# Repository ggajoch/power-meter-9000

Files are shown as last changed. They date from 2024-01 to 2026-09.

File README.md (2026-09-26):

# What is power meter 9000?

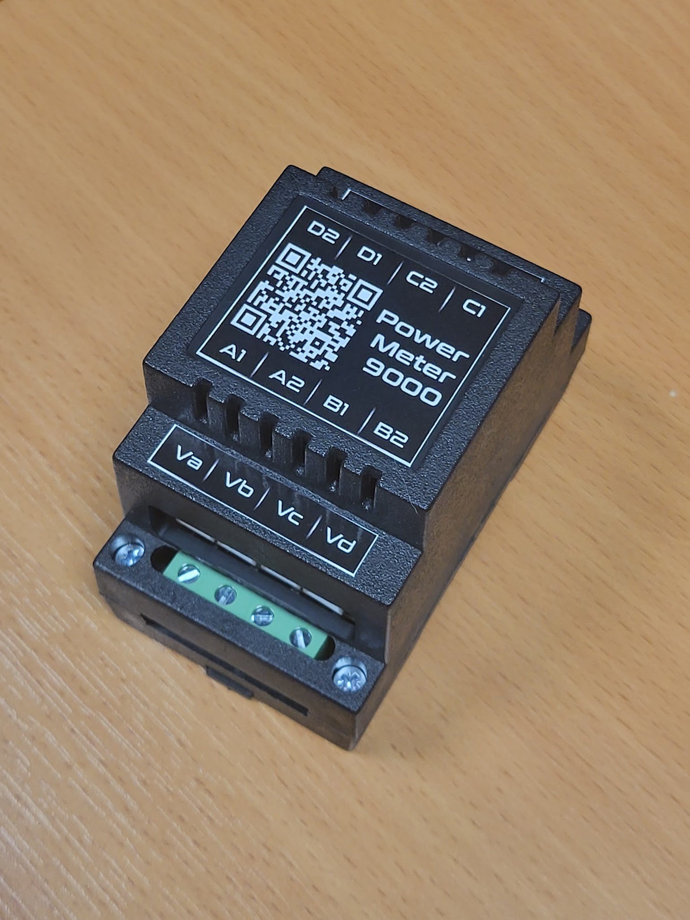
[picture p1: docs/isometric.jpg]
isometric view


Power Meter 9000 is a device to measure power drawn by electrical devices in your house. It can measure up to 8 current channels, each with 20 A current capability.

# Architecture

Power meter 9000 consists of 4 measurement channels (A, B, C, D), each with 1 voltage measurement and 2 current/power channels (total of 8 power measurements). Each channel uses BL0939 IC.

To get correct active power measurements, the current channel needs to be connected to the same phase as the corresponding voltage channels.

For example, if you have dishwasher on L1 phase, TV on L1, homelab on L2 and PC on L3 you should connect:
 - L1 to Va
 - L2 to Vb
 - L3 to Vc
 - dishwasher clamp to A1
 - TV clamp to A2
 - homelab clamp to B1
 - pc clamp to C1

Device is supplied by integrated AC-DC power supply, with power input on channel Va.

ESP32-S2 is a brain of the power meter, running esphome. Schematics/PCBs are in the repo.

# How to connect it?

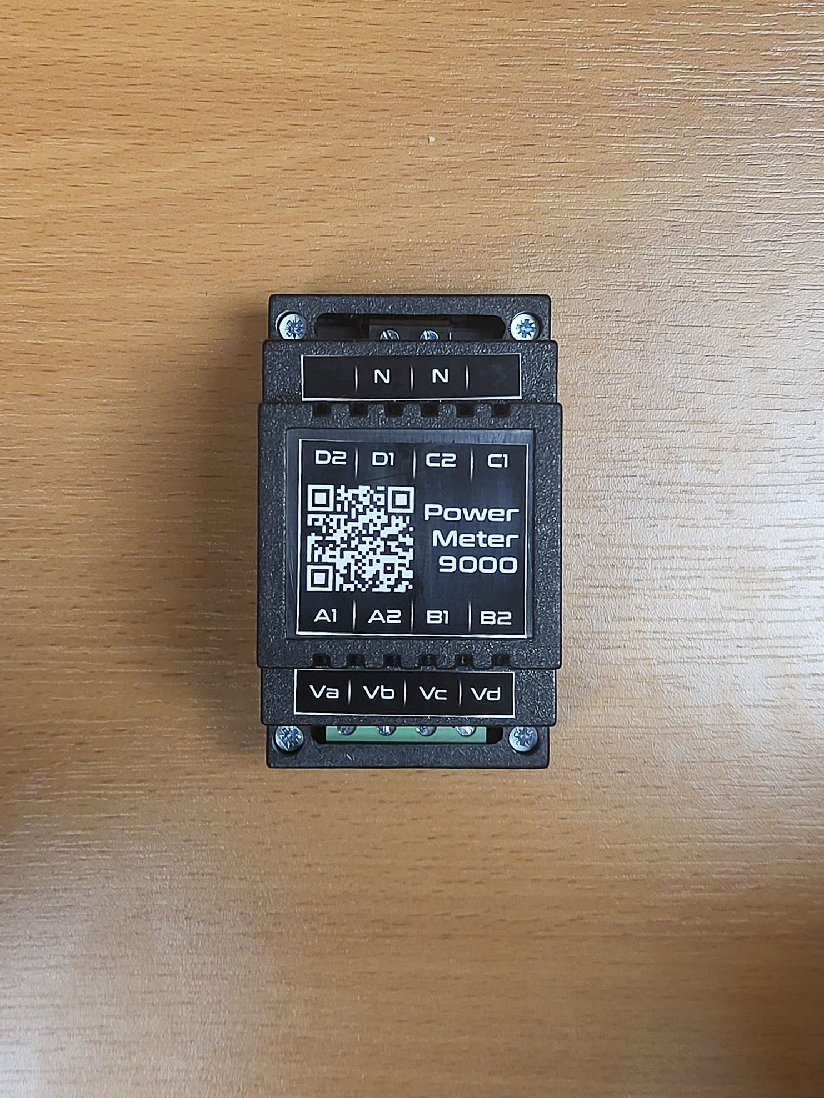
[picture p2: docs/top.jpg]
top view


 - decide on the power lines you want to measure
 - connect neutral to top terminal (either one - they are connected internally, and there are two if you would want to daisy-chain the power meters 9000)
 - for each power line, find the corresponding phase it belongs to (L1, L2, L3)
 - connect voltage inputs to corresponding terminals (Va, Vb, Vc, Vd)
 - install current clamps on the measurement lines
 - connect clamps to corresponding current input lines

# Software

Device has [`power-meter-9000.yaml`](esphome/power-meter-9000.yaml) flashed by default.

This means that the device has captive portal by default with its Wi-Fi in AP mode.

To change Wi-Fi credentials and connect to home assistant:
 - power on the device
 - connect to the Wi-Fi of the device (`power-meter-9000` with password `power-meter-9000`)
 - change Wi-Fi credentials
 - device should be discovered in Home Assistant

# But I want to flash it normally!

Sure, just **disconnect it from mains power before connecting it to computer**, undo 4 screws and connect USB to the ESP32 module. To start in bootloader, press user button during reset.

You can use https://adafruit.github.io/Adafruit_WebSerial_ESPTool/ or just esphome command line tool.

# FAQ

## My device reset itself and just don't appear on Wi-Fi

Have you re-flashed your device?

Due to the bug in the ESP32S2 modules, Wi-Fi power needs to be brought down to around 8.5 - 11 - 15 dBm for stable operation (varies on the specific copy and Wi-Fi coverage).

If you still have problems, turn the output power down.

## Weak Wi-Fi signal in electrical cabinet

By default, output_power of Wi-Fi is set to 11 dBm. If you have weak Wi-Fi, you may try increasing output_power to 15 dBm and see if that would help.

## I get correct reading of current, but power is not measured correctly

Have you connected properly current clamp to the same phase as the corresponding voltage input?

## Energy went negative or jumped after around 850 kWh

Firmware before PR #4 (September 2026) read the BL0939 energy counter as a signed 24-bit value, so a channel flipped negative after 2^23 pulses (about 851 kWh) and wrapped to 0 at about 1702 kWh. Update the firmware: the counter is now accumulated on the ESP with wrap handling, so energy grows without limit.

Negative energy is still valid when a clamp sees power flowing the other way, for example a grid feed with PV export. Energy is counted net: import adds, export subtracts.

## Energy resets to 0 after a reboot or OTA

By design. The chip keeps counting across an ESP reboot, but the firmware cannot tell how the counter got there, so every boot starts energy at 0. Home Assistant treats it as a meter reset (`total_increasing`) and keeps long-term statistics continuous. Only the consumption during the reboot itself is lost.

If a channel's energy jumps by more than `max_power` (default 10000 W per channel) times the time since the last reading, the firmware assumes the chip reset its counter (brownout) and continues from the new value. Set `max_power` on the `bl0939addr` platform if a single channel can exceed 10 kW.

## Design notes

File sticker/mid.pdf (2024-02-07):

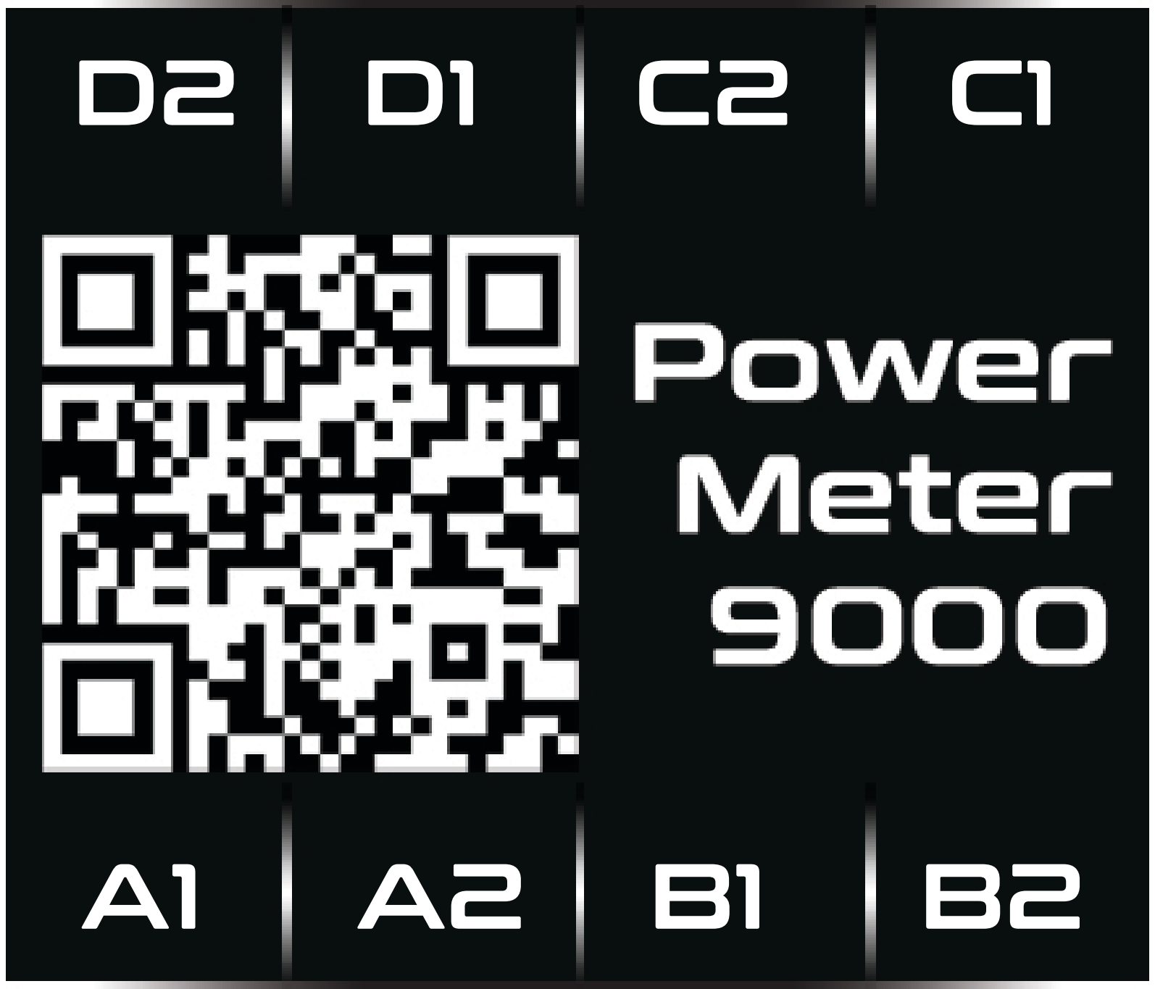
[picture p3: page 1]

D2 D1 C2 C1

A1 A2 B1 B2

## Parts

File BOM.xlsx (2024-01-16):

what? | pcs per unit | price per unit (PLN) |  | to order |  | USD/PLN | 4.02
LOWER PCB |  |  |  |  |  | units | 50
PCB from JLCPCB | 1 | 21.047916 |  |  |  | total usd to pln per unit | 0.0804
long goldpins | 1 | 0.31356 | https://pl.aliexpress.com/item/1005003012878518.html | 1
fuse | 1 | 1.371624 | https://pl.aliexpress.com/item/1005005627617019.html | 10
UPPER PCB
PCB from JLCPCB | 1 | 30.969276
goldpins 6pin | 1 | 0.471948 | https://pl.aliexpress.com/item/1005001913376271.html | 6 | TOTAL | 50pcs | unit | unit (sell 30)
ESP32 S2 | 1 | 6.947364 | https://www.aliexpress.us/item/1005006404455505.html | 50 |  | 5185.8838 | 103.717676 | 172.8627933
CURRENT TRANSFORMER
CT08CL10 | 8 | 32.16
OTHERS
nylon standoffs + screw + nut | 3 | 1.138464 | https://pl.aliexpress.com/item/1005006038666758.html | 8
self-tap screw 3x10 | 2 | 0.547524 | https://pl.aliexpress.com/item/1005006219858361.html | 3
Z102 case | 1 | 8.75 | https://www.kradex.com.pl/product/obudowy_modulowe_na_szyne_din/z102?lang=pl#options | 50

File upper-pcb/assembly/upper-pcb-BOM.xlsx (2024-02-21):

Comment | Designator | Footprint | JLCPCB Part #（optional）
C_33nF_50V_X7R_0603_10 | C1_CH1, C1_CH2, C1_CH3, C1_CH4, C2_CH1, C2_CH2, C2_CH3, C2_CH4, C3_CH1, C3_CH2, C3_CH3, C3_CH4, C4_CH1, C4_CH2, C4_CH3, C4_CH4, C5_CH1, C5_CH2, C5_CH3, C5_CH4, C7_CH1, C7_CH2, C7_CH3, C7_CH4, C8_CH1, C8_CH2, C8_CH3, C8_CH4 | C_0603_1608 | C21117
C_100nF_50V_X7R_0603_5 | C6_CH1, C6_CH2, C6_CH3, C6_CH4, C9, C10 | C_0603_1608 | C14663
P_HEADER_2x8_2.54_VERTICAL | M1, M2 | P_HEADER_2x8_2.54_VERTICAL | C30734
P_XHB-2AW | P1_CH1, P1_CH2, P1_CH3, P1_CH4, P2_CH1, P2_CH2, P2_CH3, P2_CH4 | P_XHB-2AW | C3011964
R_1k_0603_1 | R1_CH1, R1_CH2, R1_CH3, R1_CH4, R3_CH1, R3_CH2, R3_CH3, R3_CH4, R4_CH1, R4_CH2, R4_CH3, R4_CH4, R6_CH1, R6_CH2, R6_CH3, R6_CH4, R8_CH1, R8_CH2, R8_CH3, R8_CH4 | R_0603_1608 | C21190
R_3.3R_0603_5 | R2_CH1, R2_CH2, R2_CH3, R2_CH4, R5_CH1, R5_CH2, R5_CH3, R5_CH4 | R_0603_1608 | C103612
R_27k_0603_1 | R7_CH1, R7_CH2, R7_CH3, R7_CH4 | R_0603_1608 | C22967
U_BL0939 | U1_CH1, U1_CH2, U1_CH3, U1_CH4 | SSOP20_3.9x8.65 | C2841044
C_10uF_25V_X7S_0805_10 | C11, C12 | C_0805_2012 | C15850
 |  |  |  | Mouser | 603-RC1206FR-07499KL | 0.025 | 0.5 | Warning
 |  |  |  | TME | RC1206FR-07100K |  |  | Fatal error
 |  |  |  | LCSC | C209903 | 2.17 | 2.17 | Error

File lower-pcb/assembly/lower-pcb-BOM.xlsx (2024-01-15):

Comment | Designator | Footprint | JLCPCB Part #（optional）
CE_220uF_16V_AL2O3_10x16x5_20 | C1 | CE_D_10x16x5_THT | C2896719
J_DG128-7.5-02P-14 | J1 | DG128-7.5-02P-14 | C557657
J_DG128-7.5-04P-14 | J2 | DG128-7.5-04P-14 | C2997280
MOV_385VDC_300VAC_THT | MOV1 | MOV_AXIAL_7.5_3.5 | C2839517
R_499k_1206_1 | R1, R2, R3, R4, R5, R7, R8, R9, R10, R11, R13, R14, R15, R16, R17, R19, R20, R21, R22, R23 | R_1206_3216 | C3152280
R_100k_1206_1 | R6, R12, R18, R24, R26, R27, R28, R29 | R_1206_3216 | C17900
VS_HLK-PM01 | U1 | VS_HLK-PMxx | C209903
 |  |  |  | Mouser | 667-EEU-FC1C681 | 0.69 | 0.69 | Warning
 |  |  |  | TME | 883114 |  |  | Fatal error
 |  |  |  | TME | DG128-7.5-02P14 |  |  | Fatal error
 |  |  |  | TME |  |  |  | Fatal error
 |  |  |  | TME | ZL201-06G |  |  | Fatal error
 |  |  |  | Mouser | 603-RC1206FR-07499KL | 0.025 | 0.5 | Warning
 |  |  |  | TME | RC1206FR-07100K |  |  | Fatal error
 |  |  |  | LCSC | C209903 | 2.17 | 2.17 | Error

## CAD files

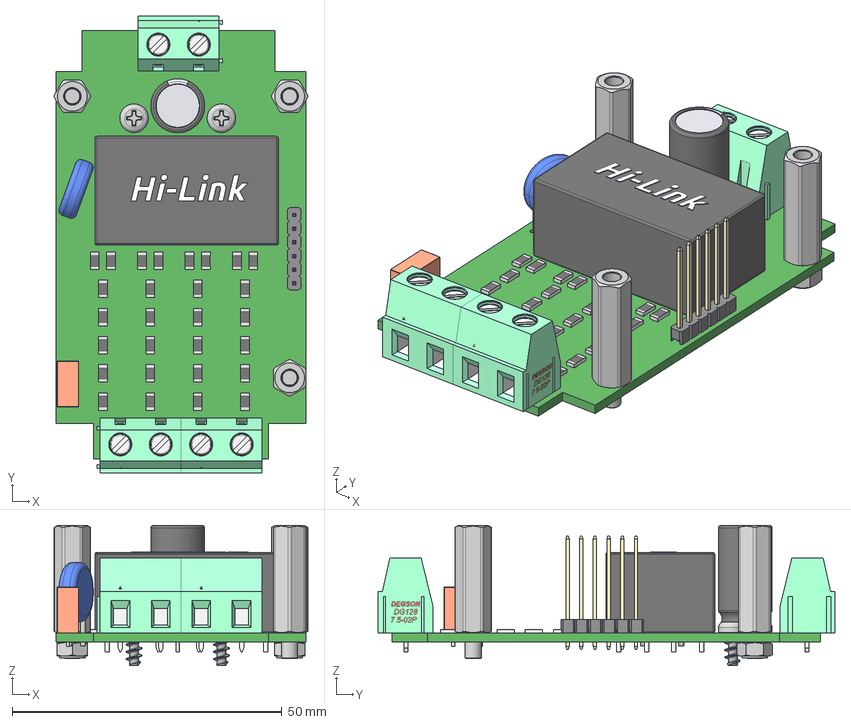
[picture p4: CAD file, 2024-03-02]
lower-pcb/assembly/lower-pcb.step
47.0 x 84.7 x 26.0 mm
te5
RES 1206 (3216 metric) x 28
ElectroCap20x10mm Leads
ElectroCap20x10mm Body
ElectroCap20x10mm Stripe
Hi-Link HiLink HLK-PM v1
DG128-7.5-02P-14-00AH v1 x 3
standoff x 3
m3nut x 2
screw x 2
User Library-MOV-10D561K

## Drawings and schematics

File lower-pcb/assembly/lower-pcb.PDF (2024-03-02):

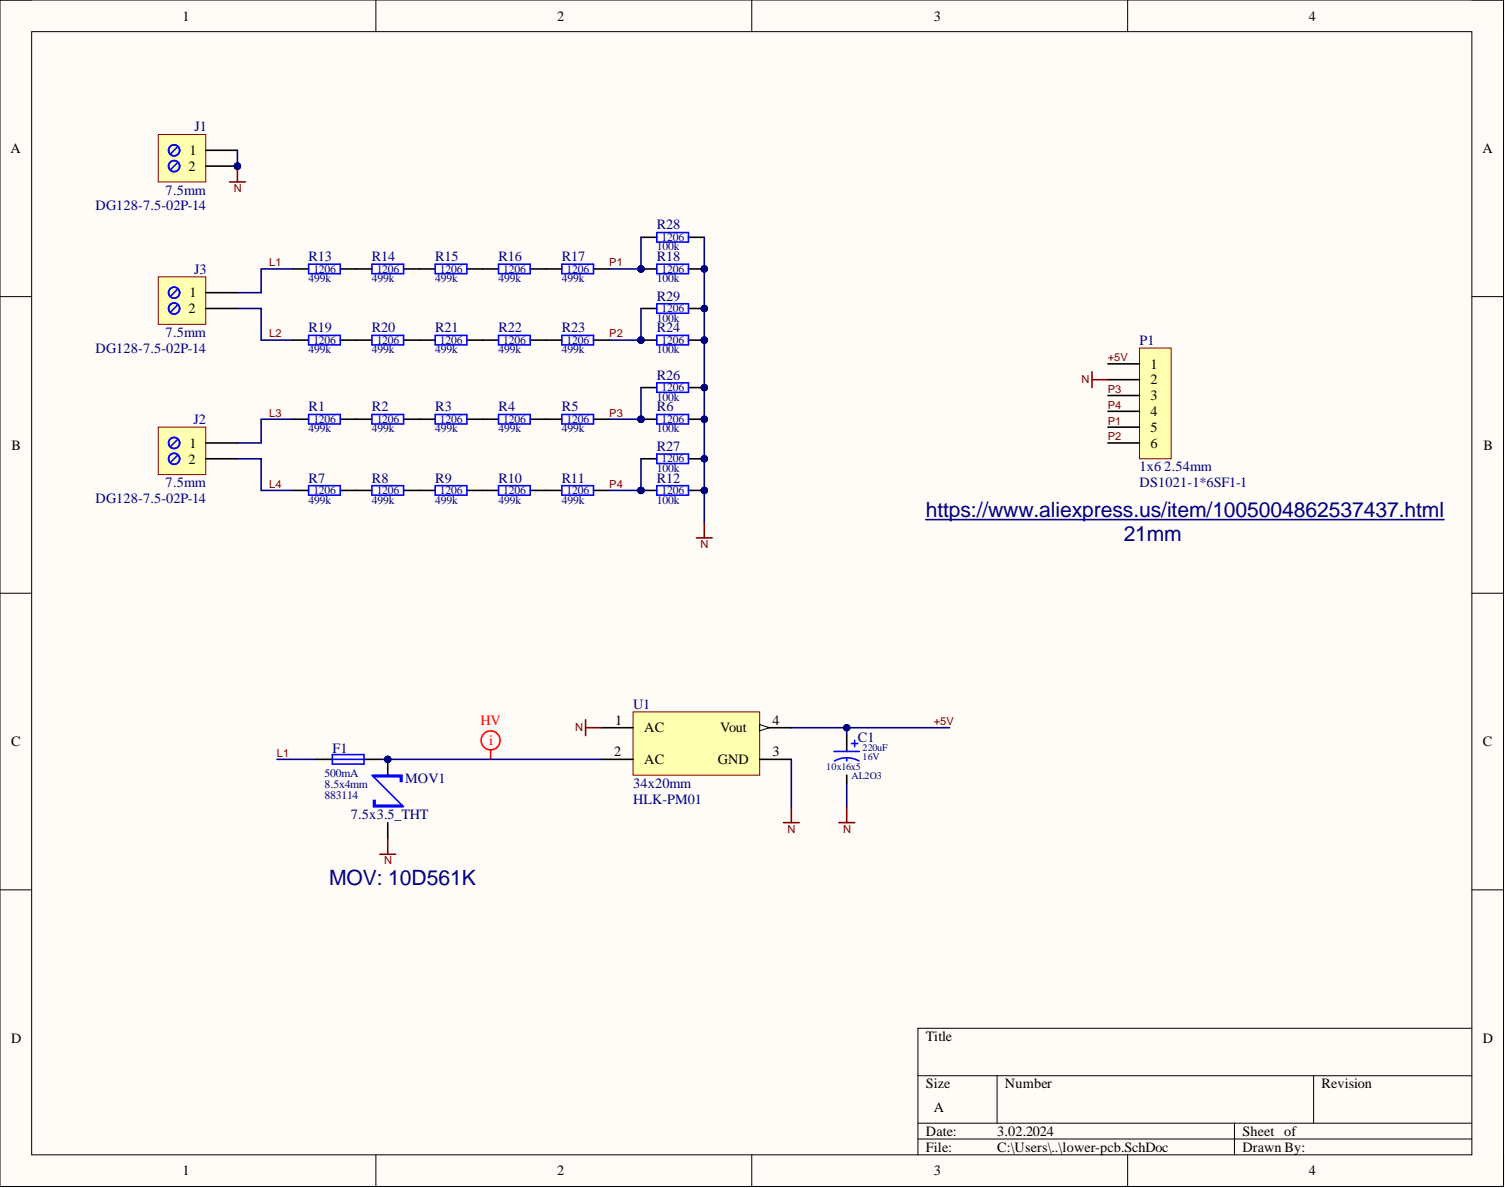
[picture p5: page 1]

https://www.aliexpress.us/item/1005004862537437.html

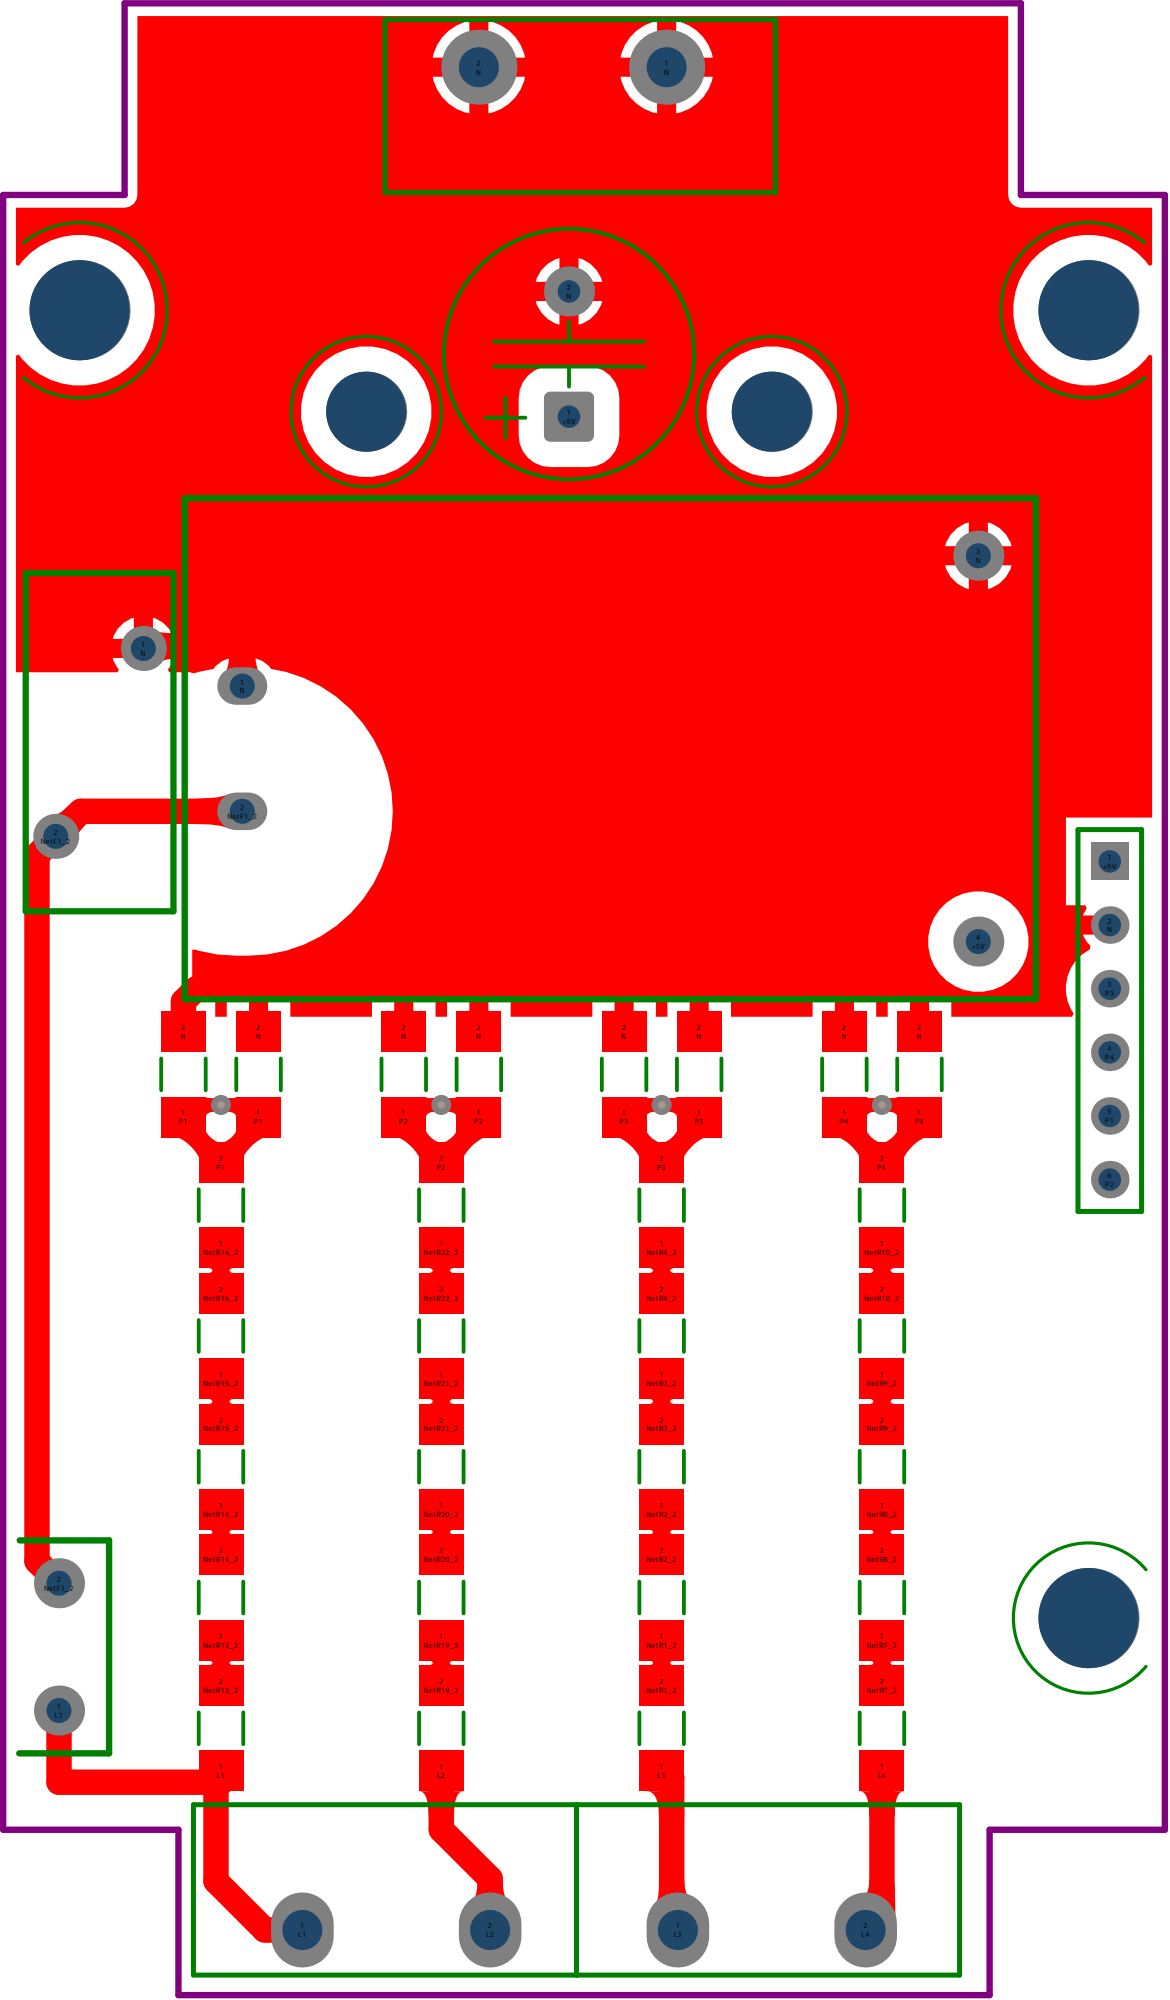
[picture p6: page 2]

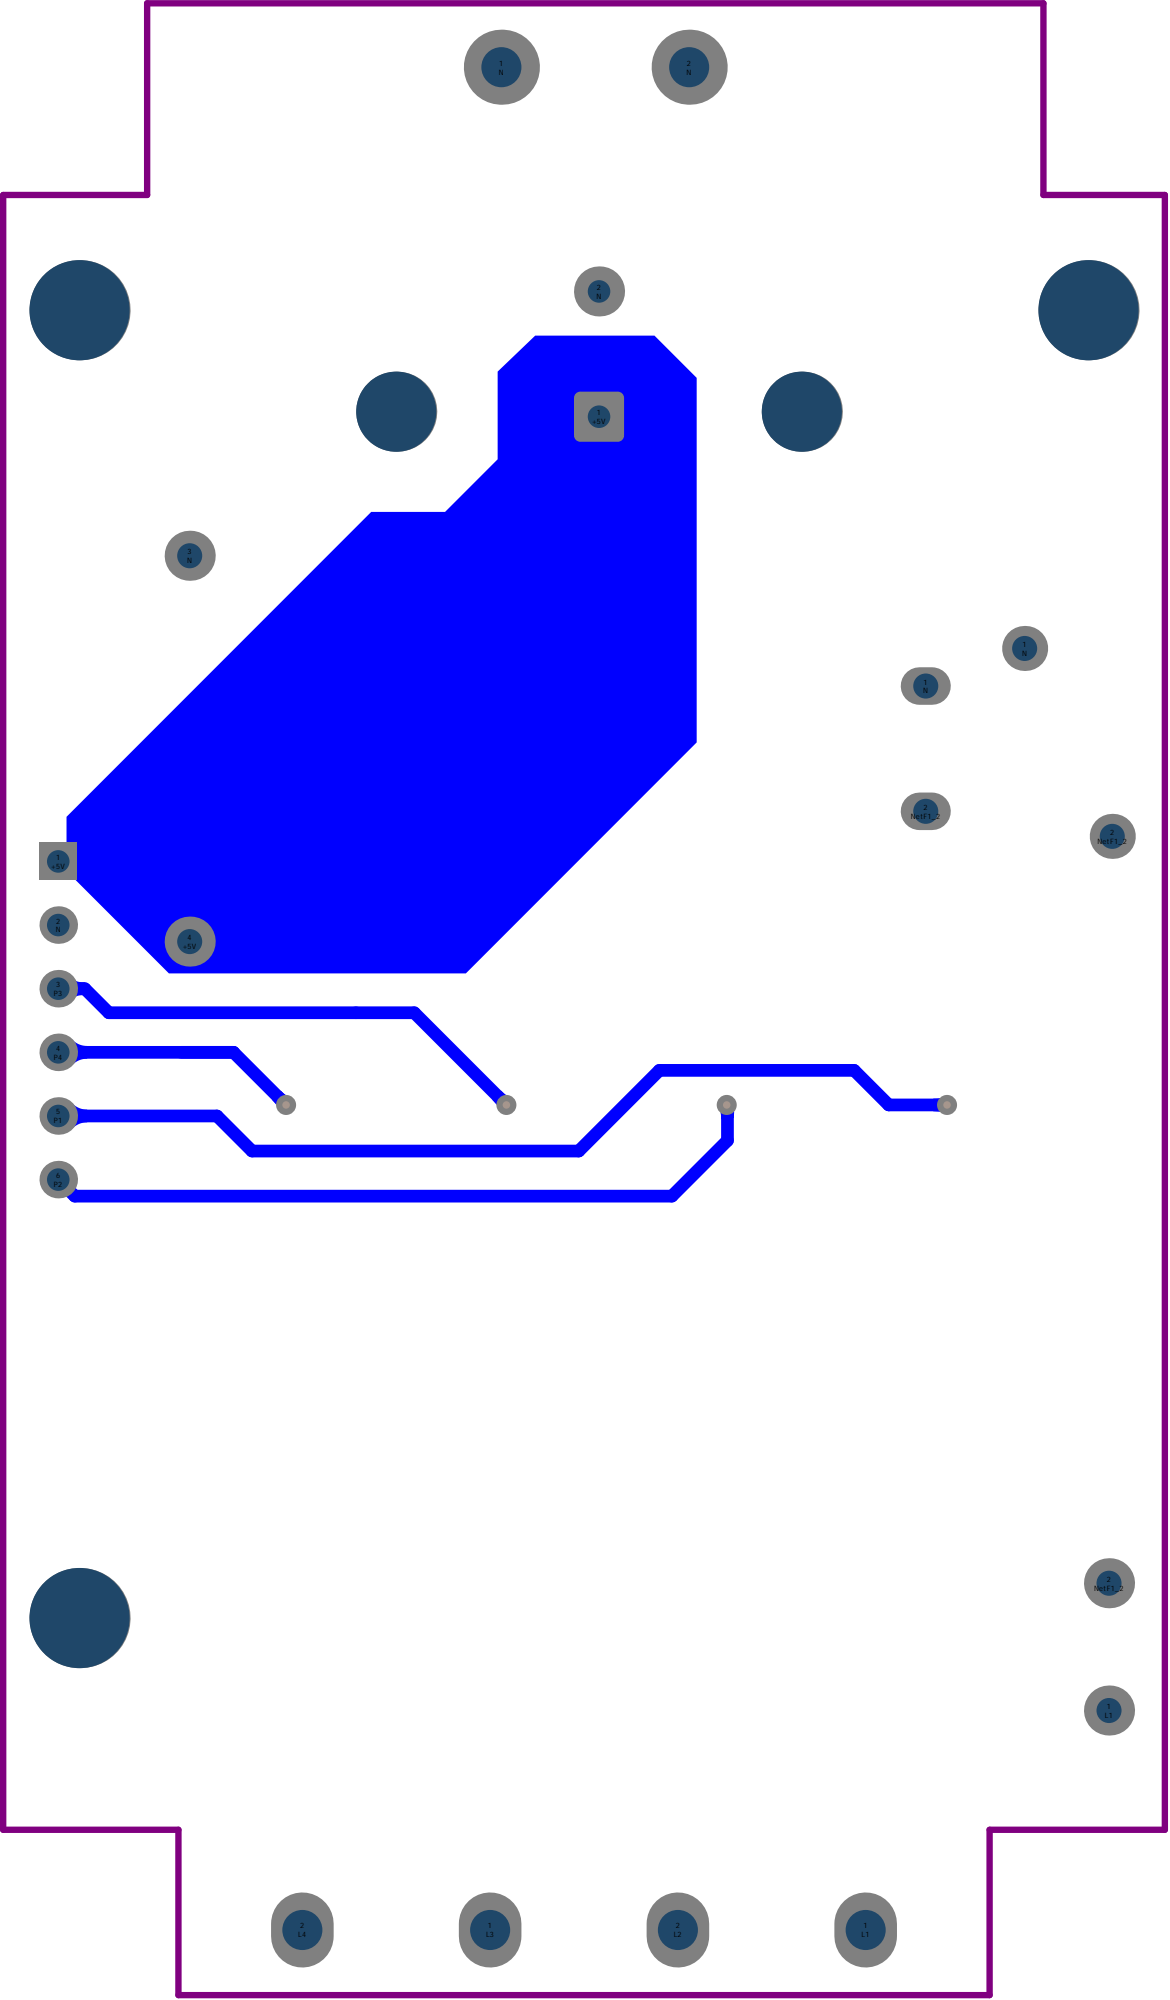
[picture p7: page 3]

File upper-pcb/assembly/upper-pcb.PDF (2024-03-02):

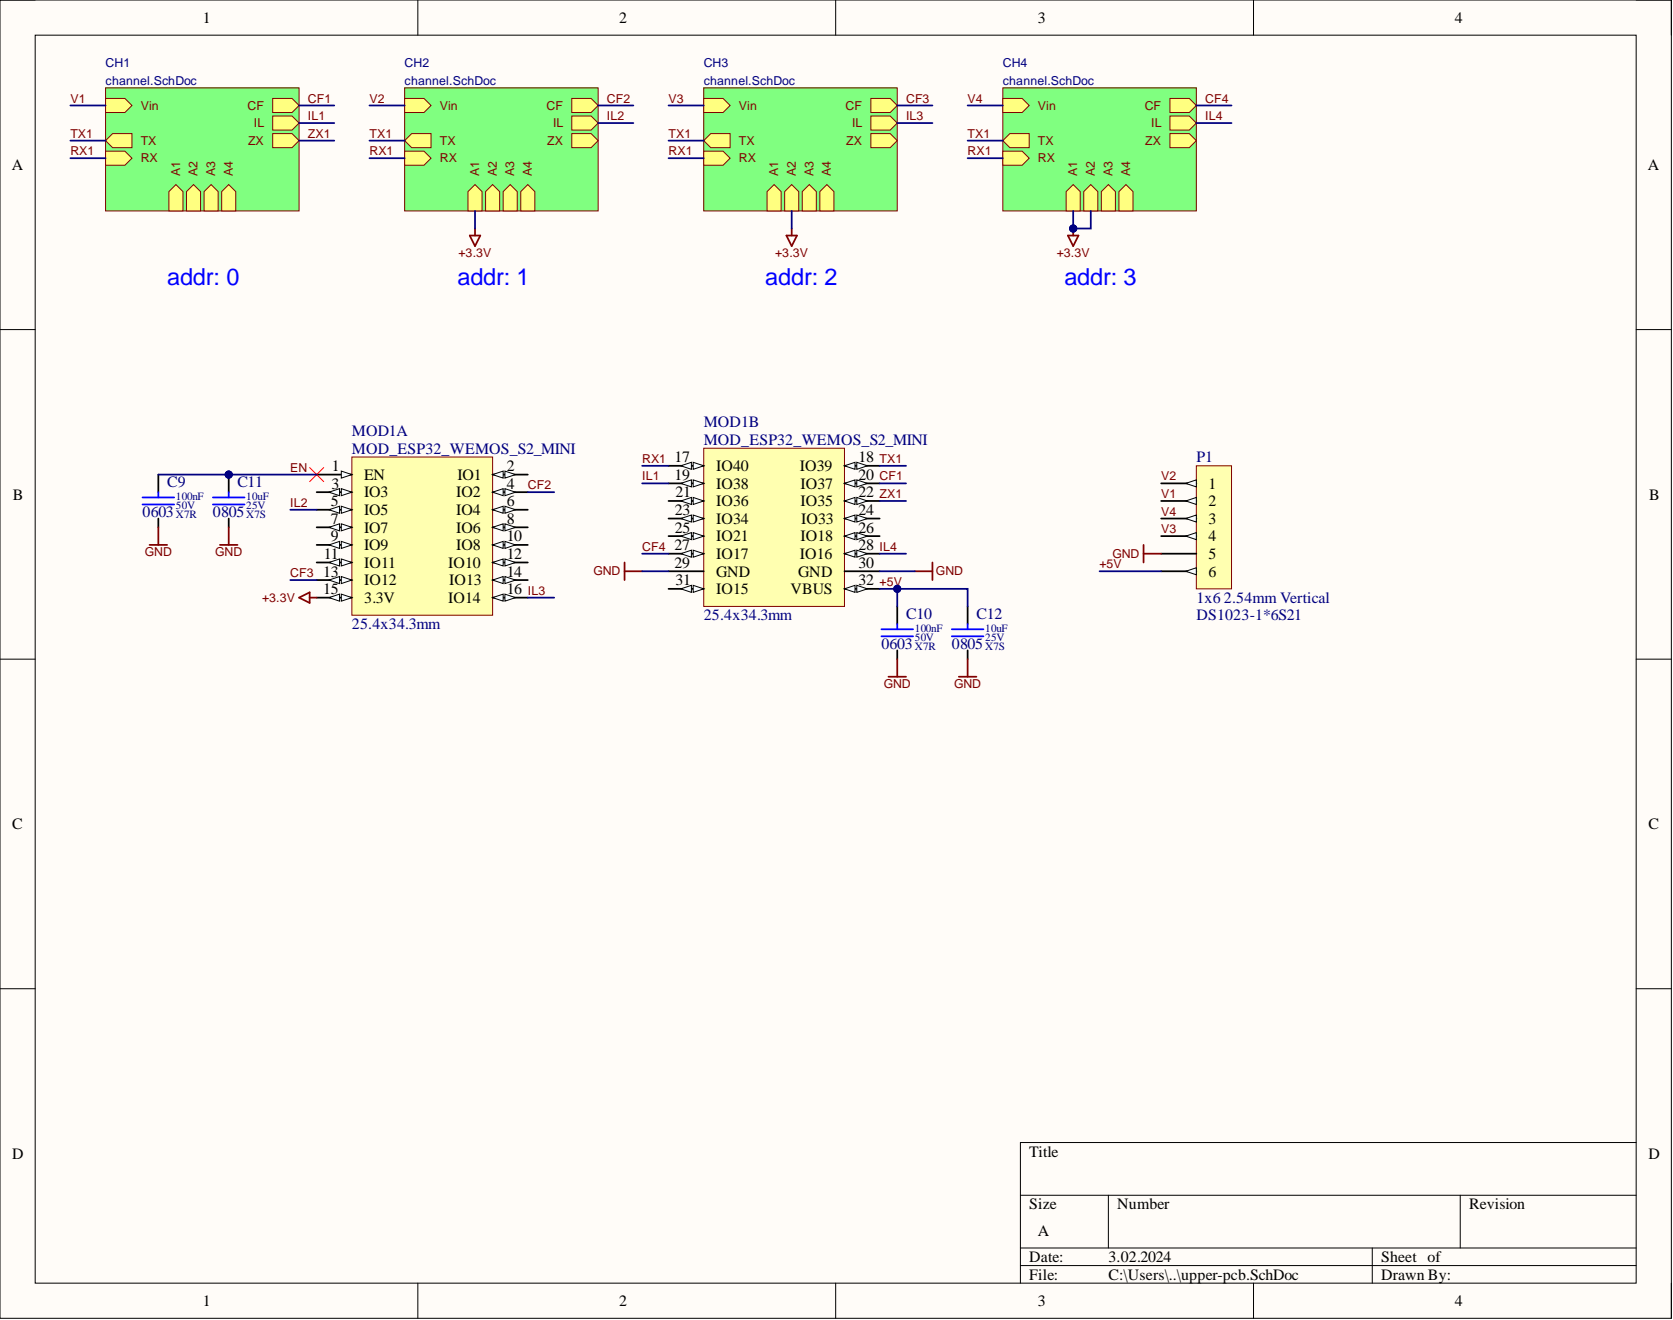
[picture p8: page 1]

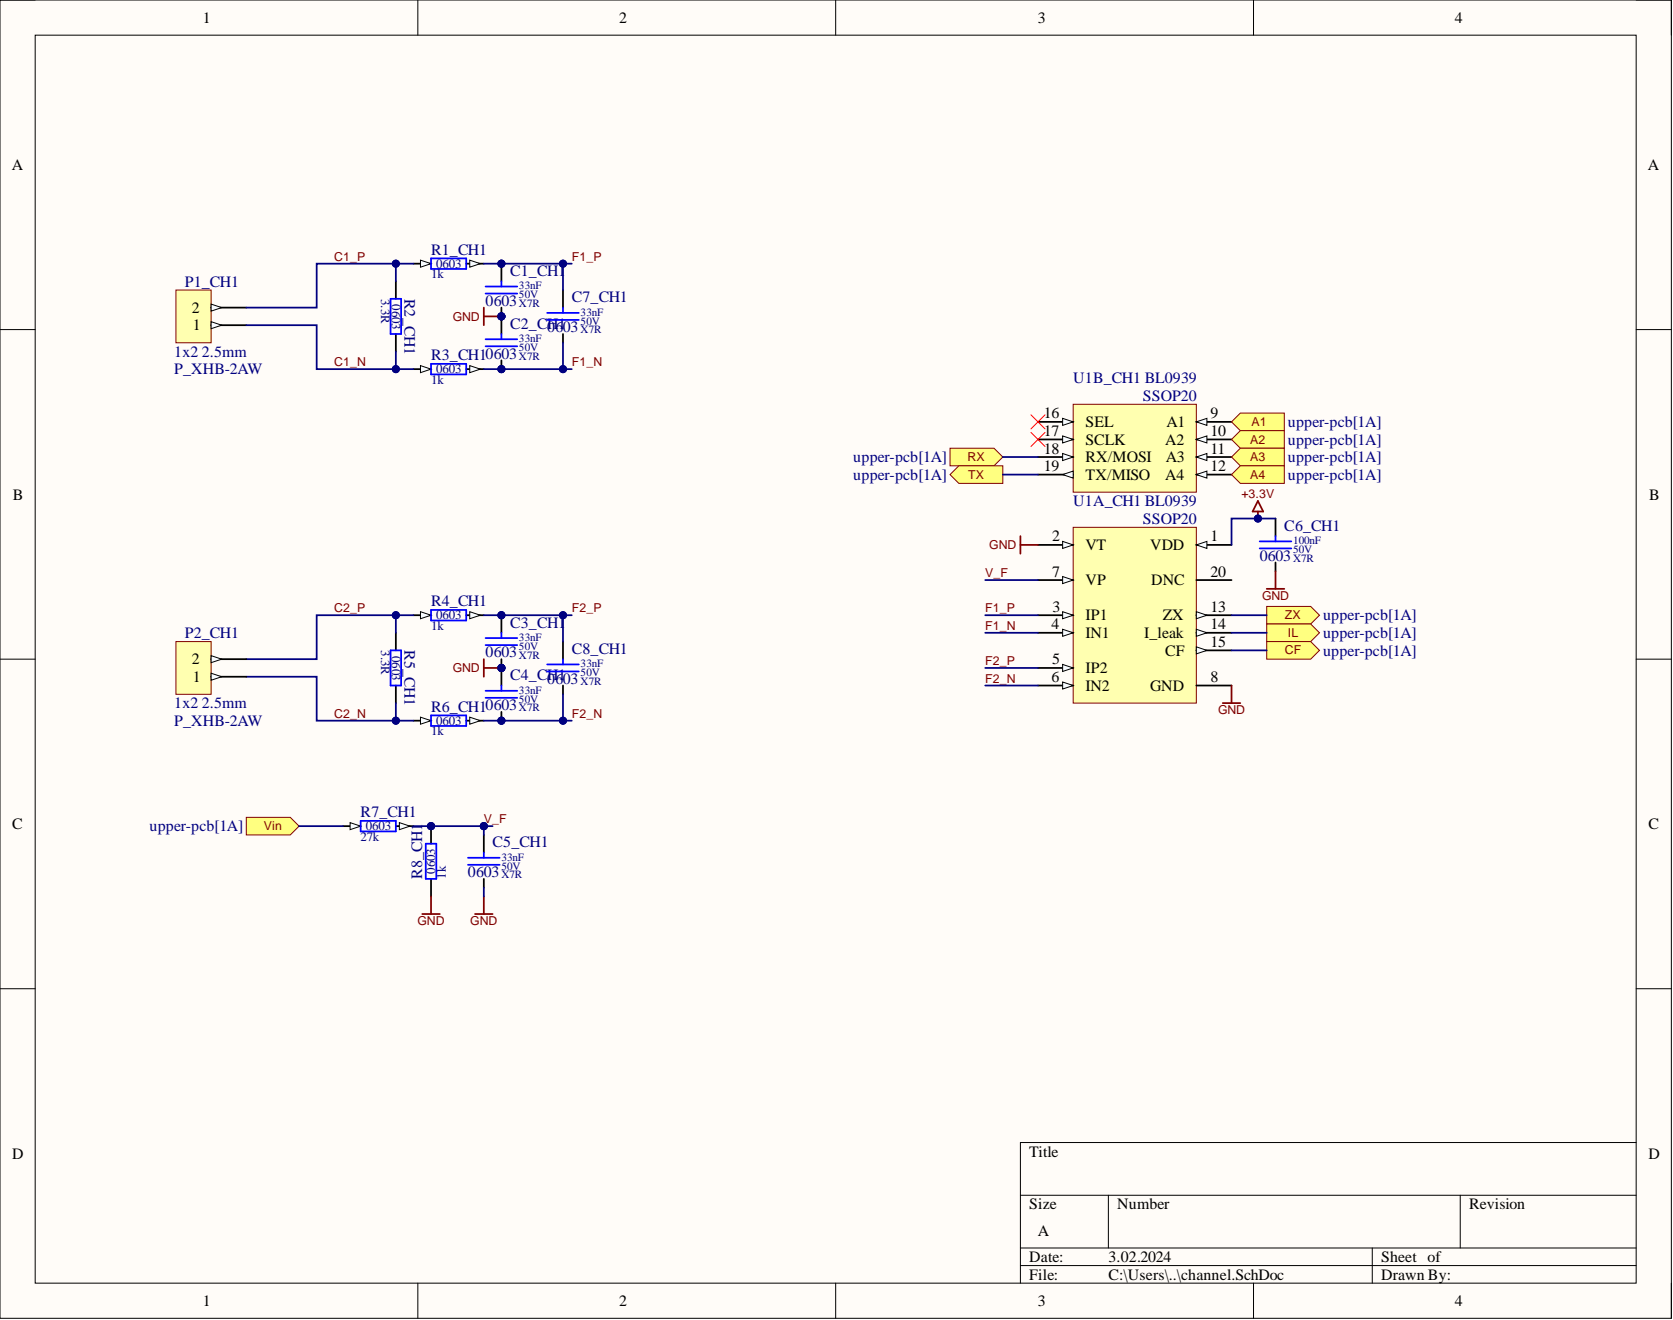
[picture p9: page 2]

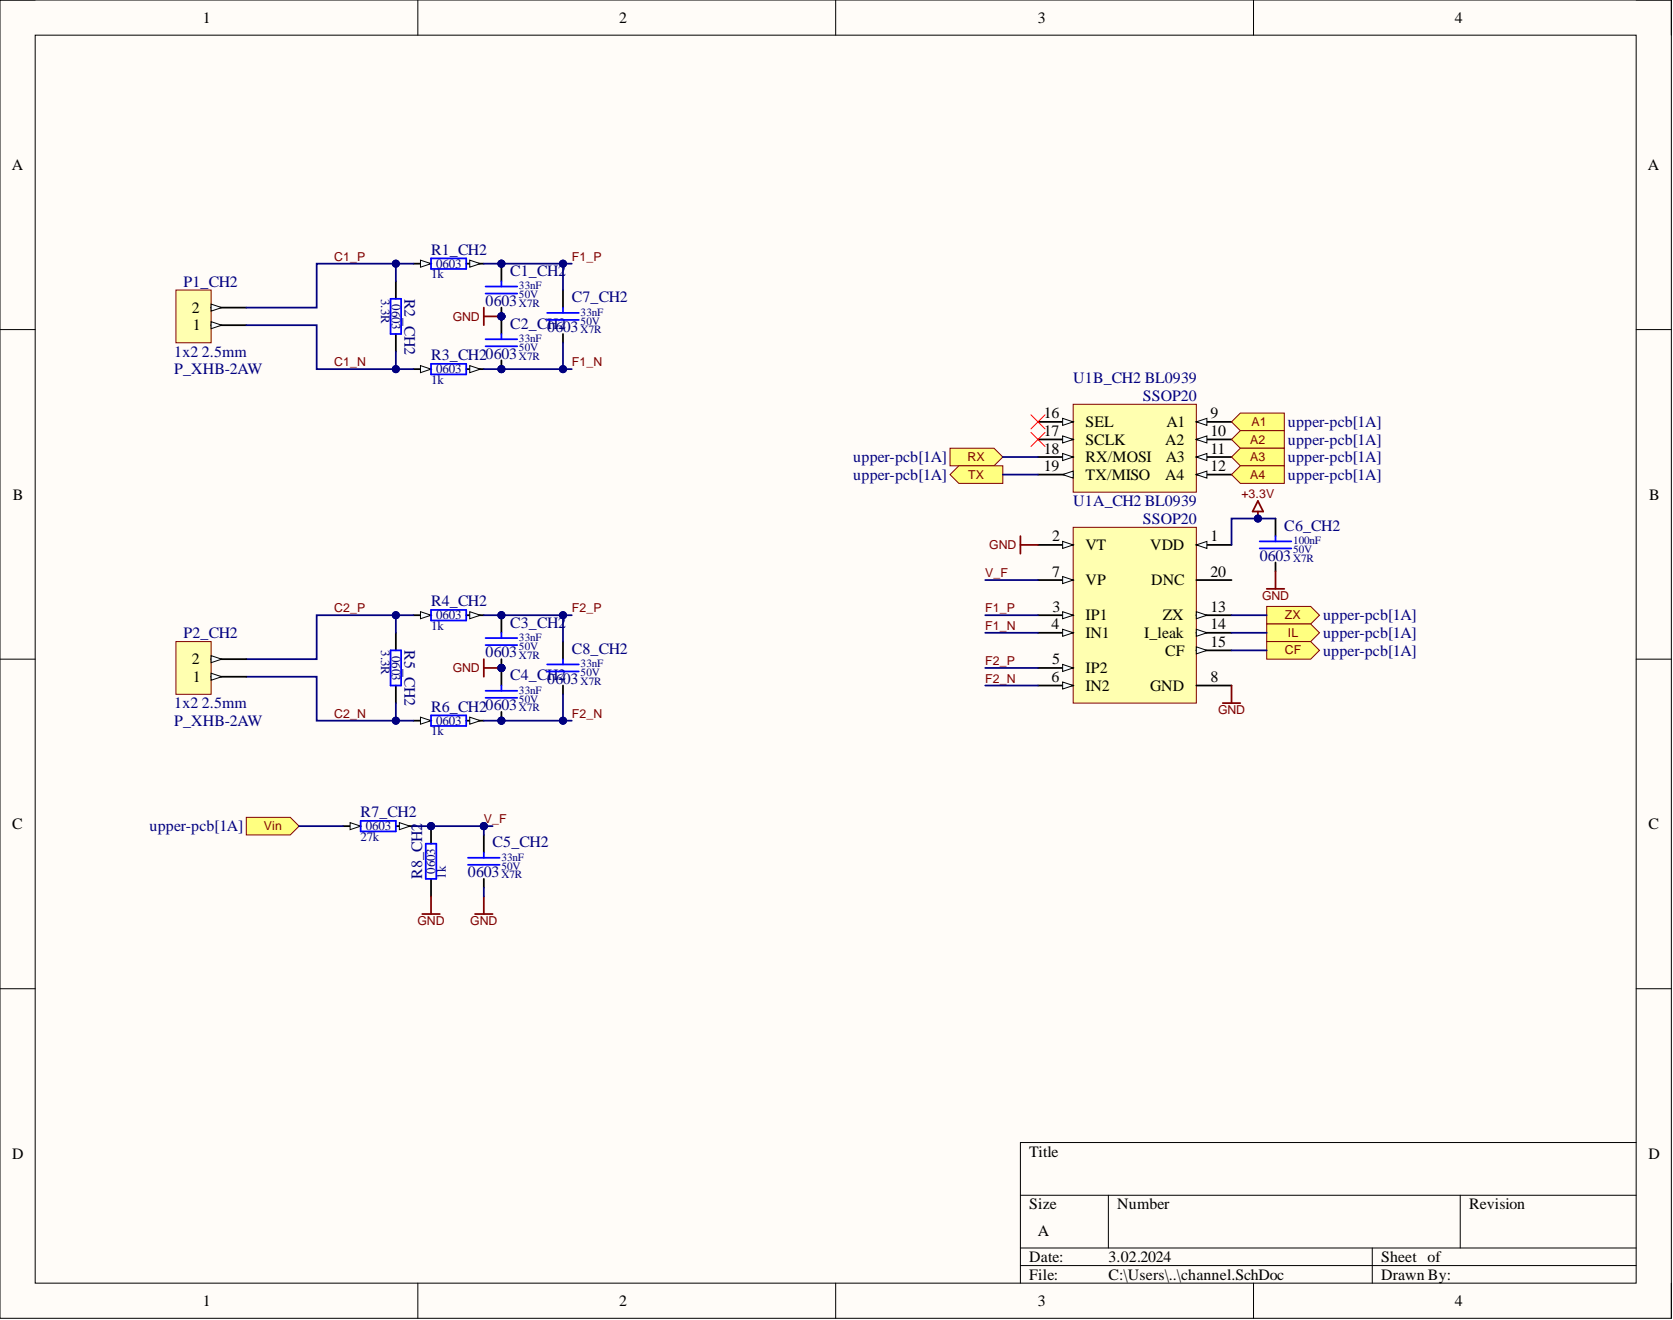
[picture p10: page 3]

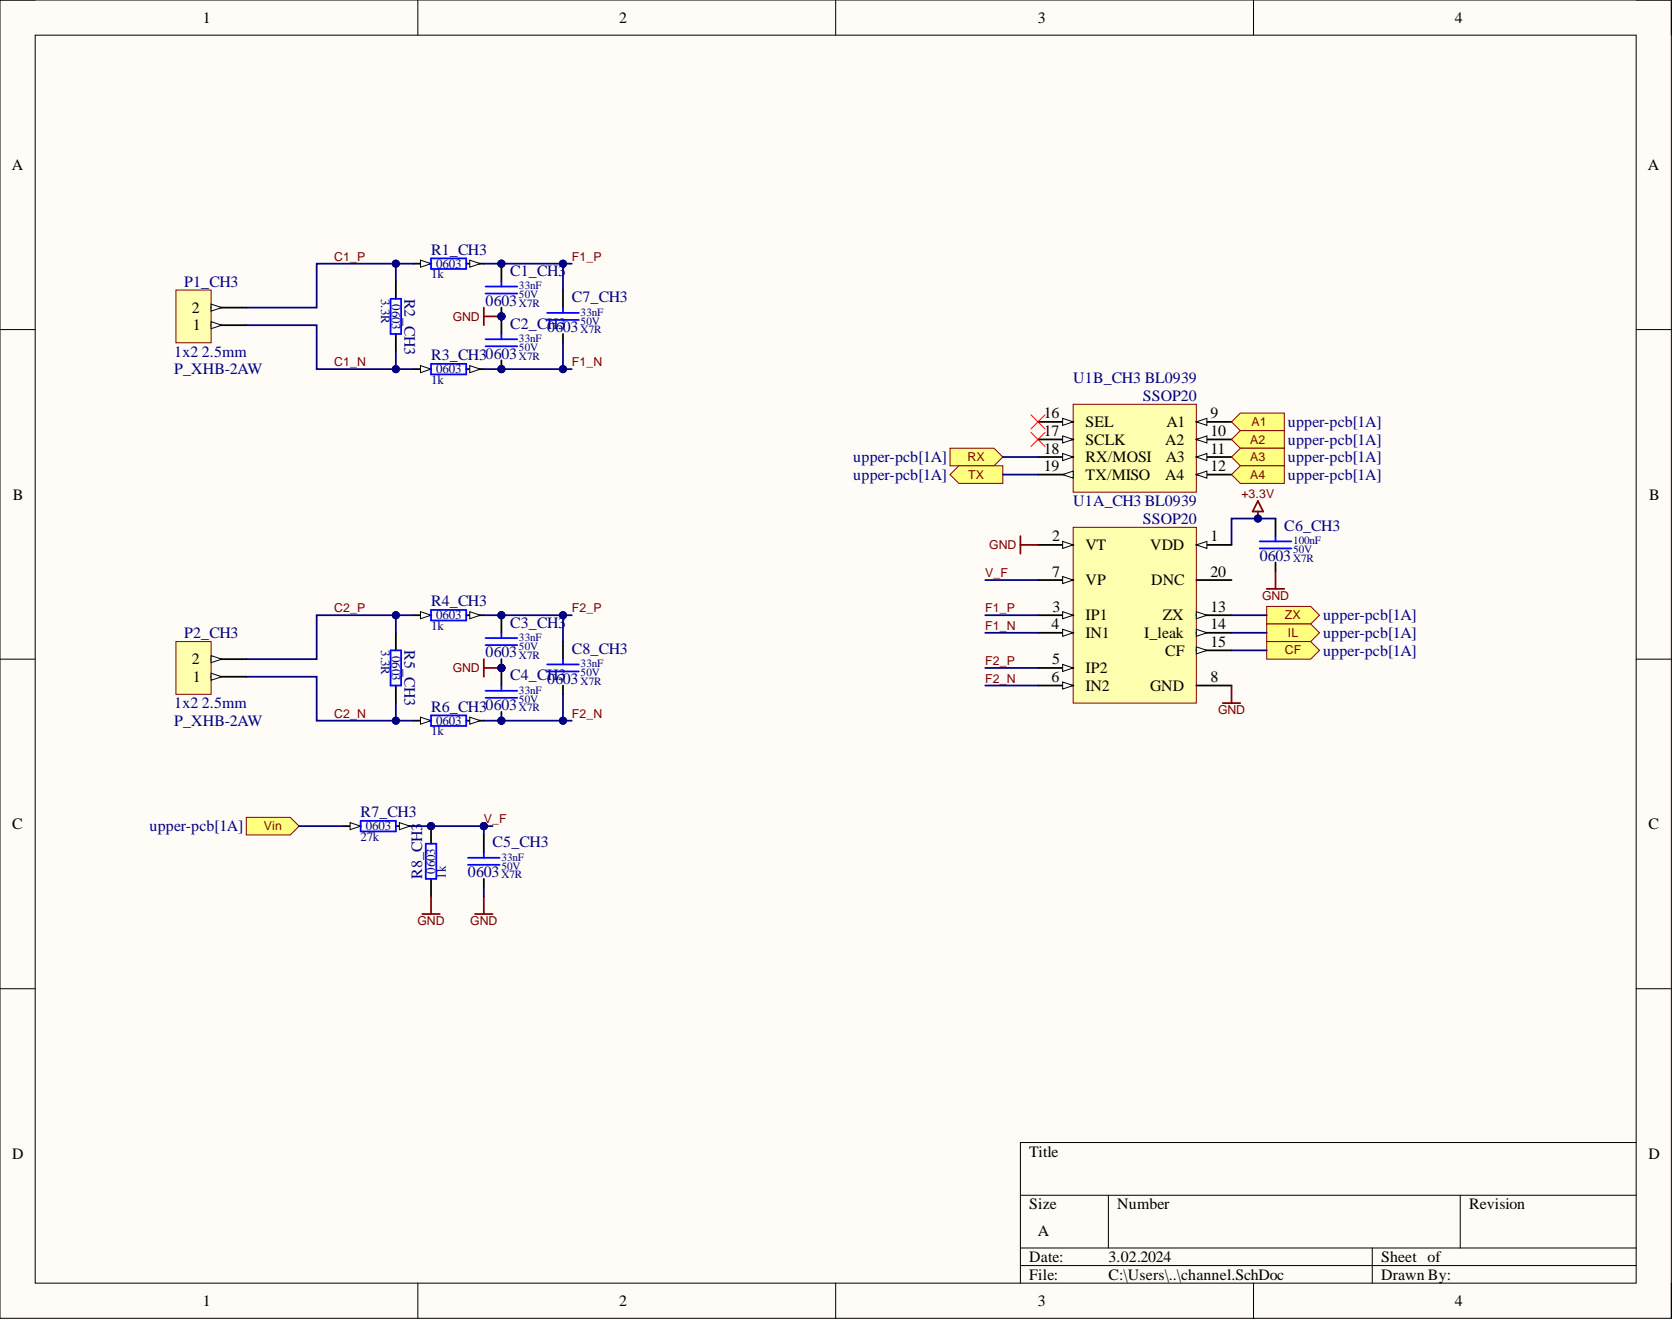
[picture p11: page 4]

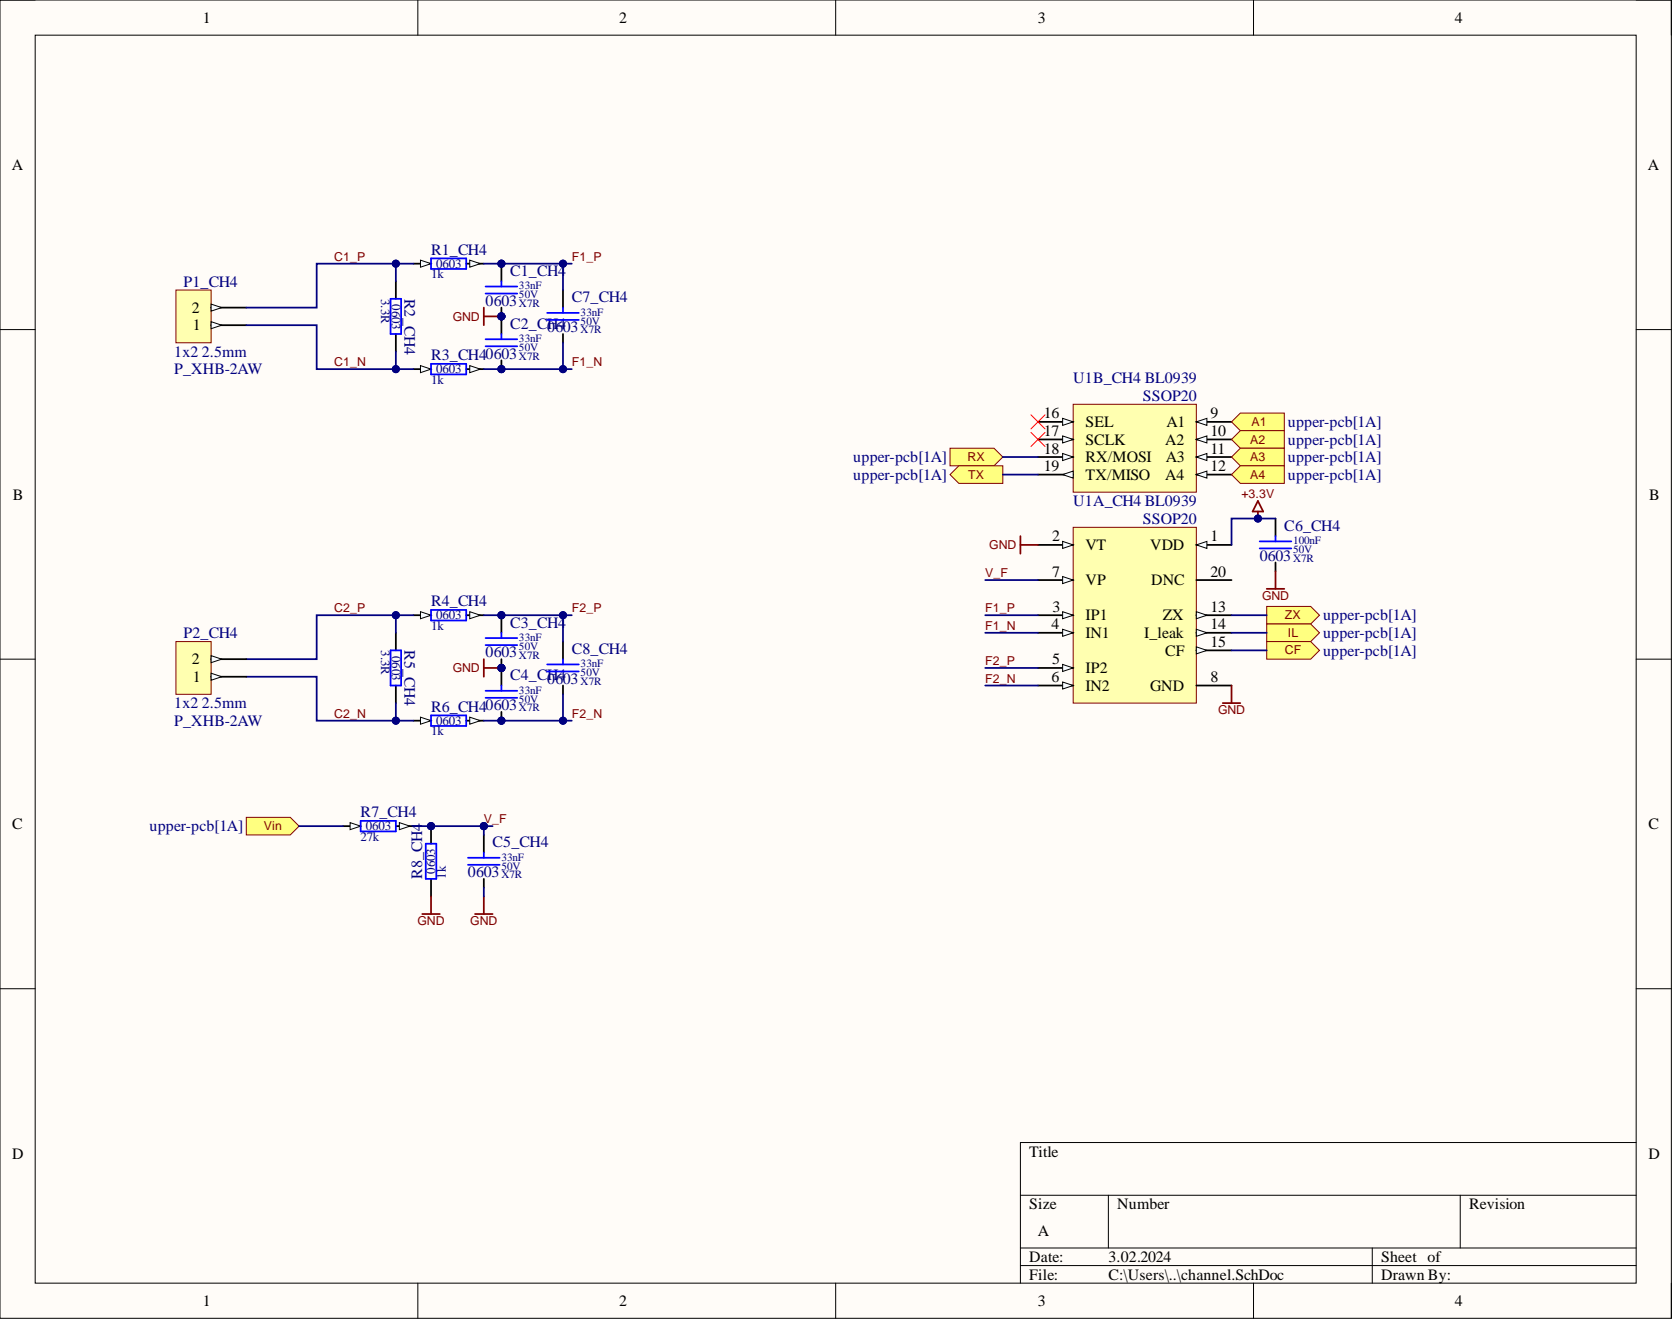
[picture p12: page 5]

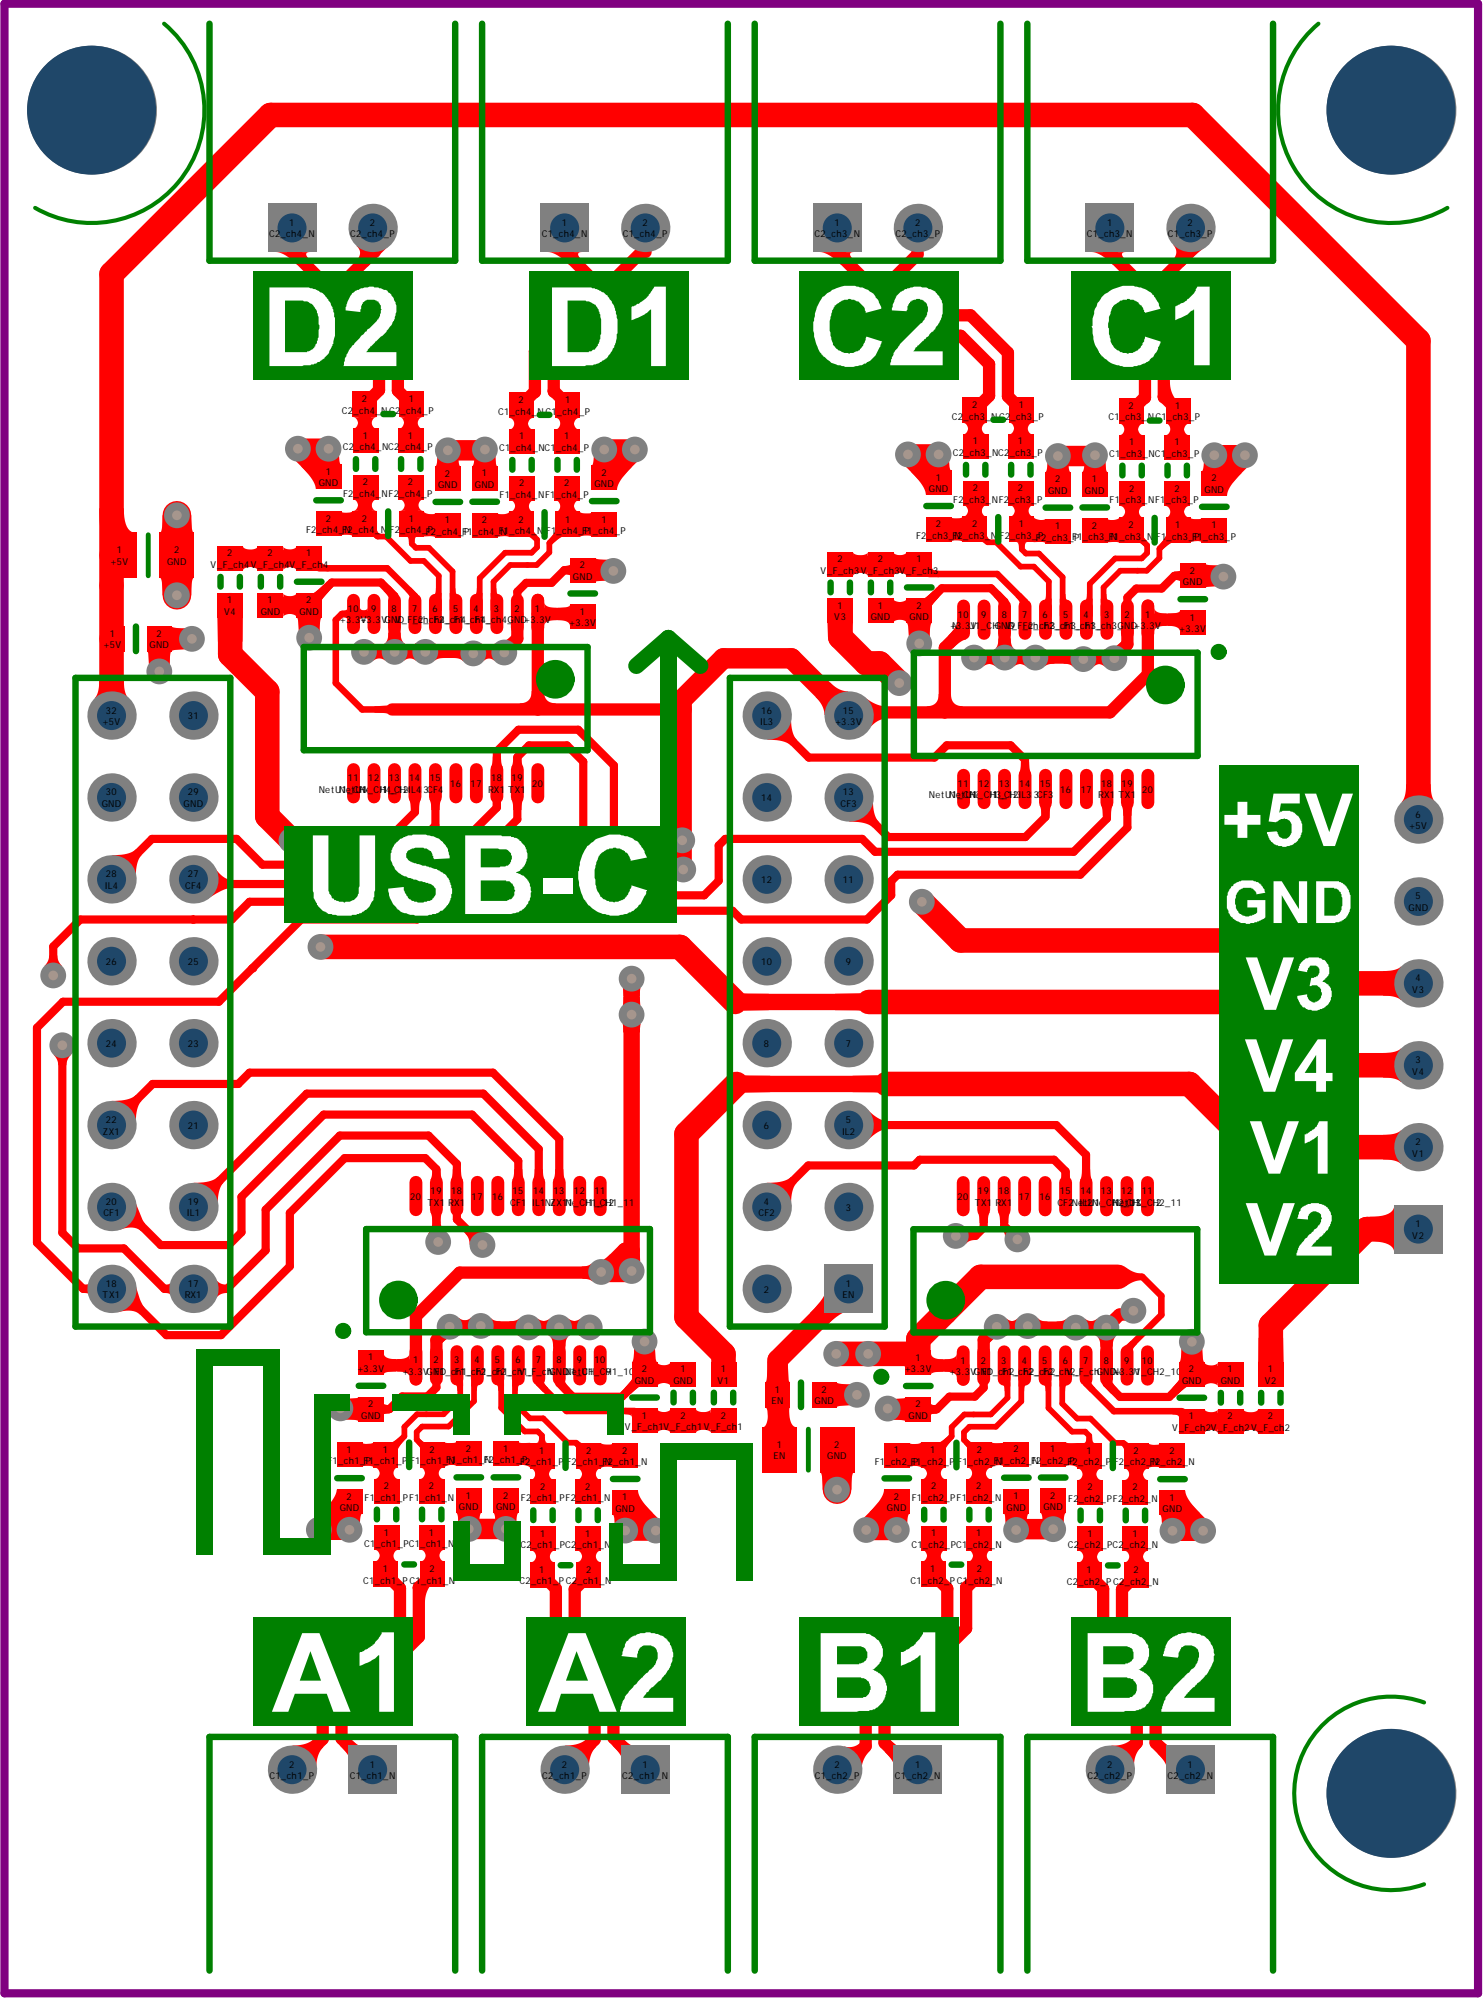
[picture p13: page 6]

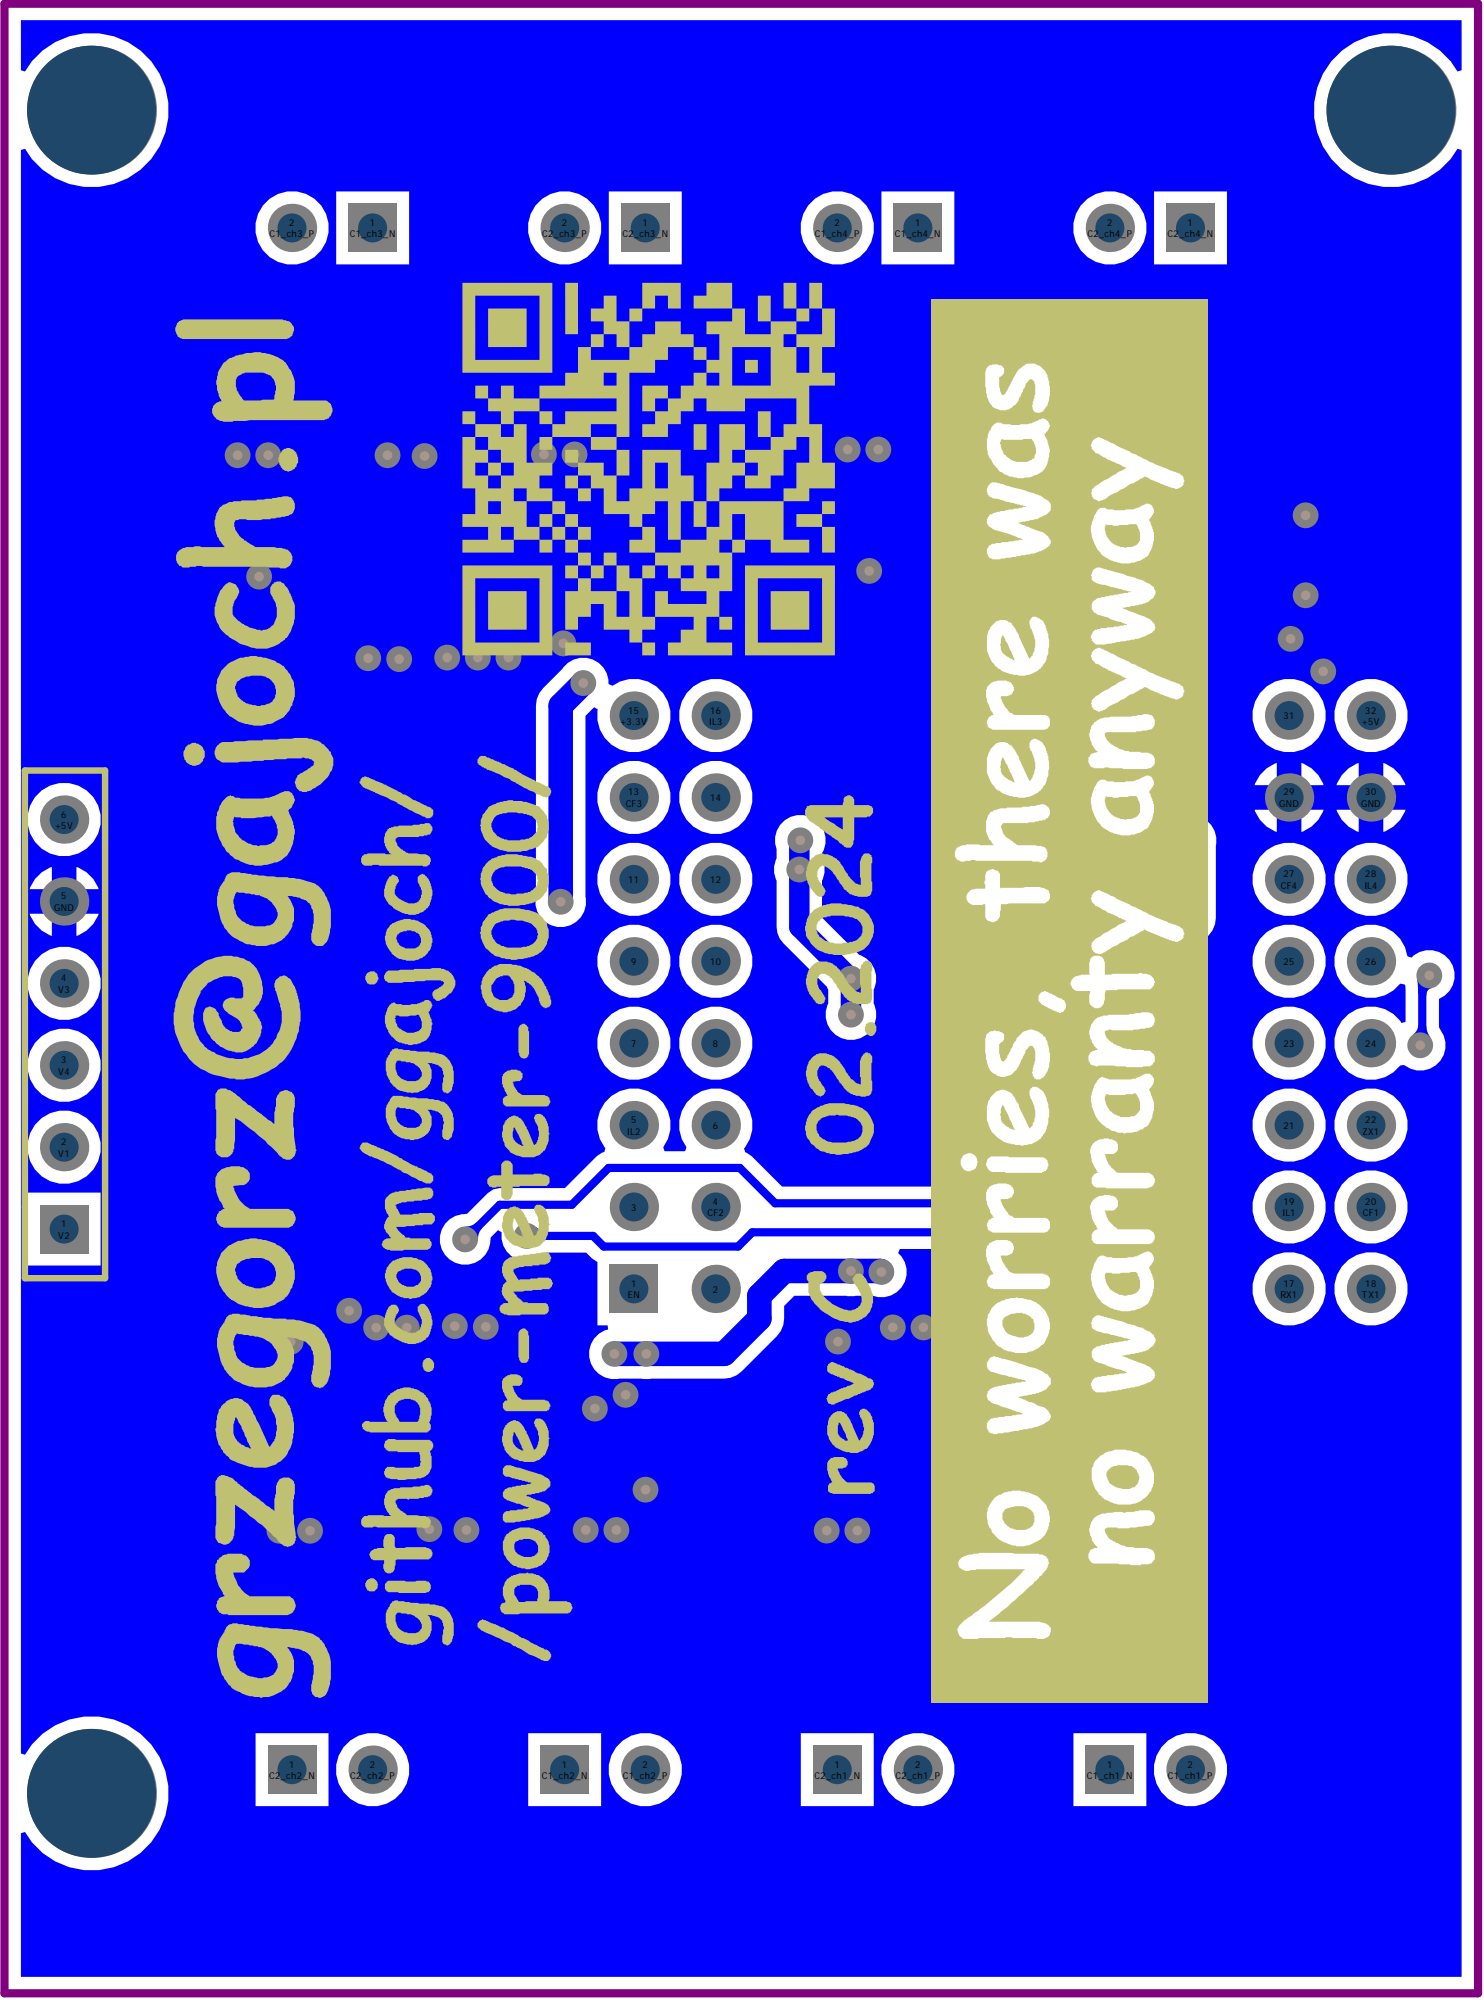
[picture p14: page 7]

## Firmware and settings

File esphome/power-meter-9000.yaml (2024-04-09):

esphome:
  name: power-meter-9000
  name_add_mac_suffix: true

esp32:
  board: lolin_s2_mini
  framework:
    type: arduino

# Enable logging
logger:
  level: WARN

api:

ota:

wifi:
  output_power: 11

  # Enable hotspot (captive portal) to provision WiFi
  ap:
    ssid: power-meter-9000
    password: power-meter-9000

captive_portal:

uart:
  tx_pin: GPIO40
  rx_pin: GPIO39
  baud_rate: 4800
  parity: NONE
  stop_bits: 1

external_components:
    source: github://ggajoch/power-meter-9000

sensor:
  - platform: uptime
    name: Uptime
  - platform: bl0939addr
    id: chA
    update_interval: 10s
    voltage:
      name: 'v_A'
    current_1:
      name: 'c_A1'
    current_2:
      name: 'c_A2'
    active_power_1:
      name: 'p_A1'
    active_power_2:
      name: 'p_A2'
    energy_1:
      name: 'e_A1'
    energy_2:
      name: 'e_A2'
    energy_total:
      name: 'e_A'
    address: 0
    current_reference: 438921.675
    voltage_reference: 16740.165
    power_reference: 1147.908
    energy_reference: 9852.572

  - platform: bl0939addr
    id: ch1
    update_interval: 10s
    voltage:
      name: 'v_B'
    current_1:
      name: 'c_B1'
    current_2:
      name: 'c_B2'
    active_power_1:
      name: 'p_B1'
    active_power_2:
      name: 'p_B2'
    energy_1:
      name: 'e_B1'
    energy_2:
      name: 'e_B2'
    energy_total:
      name: 'e_B'
    address: 1
    current_reference: 438921.675
    voltage_reference: 16740.165
    power_reference: 1147.908
    energy_reference: 9852.572
  
  - platform: bl0939addr
    id: ch2
    update_interval: 10s
    voltage:
      name: 'v_C'
    current_1:
      name: 'c_C1'
    current_2:
      name: 'c_C2'
    active_power_1:
      name: 'p_C1'
    active_power_2:
      name: 'p_C2'
    energy_1:
      name: 'e_C1'
    energy_2:
      name: 'e_C2'
    energy_total:
      name: 'e_C'
    address: 2
    current_reference: 438921.675
    voltage_reference: 16740.165
    power_reference: 1147.908
    energy_reference: 9852.572

  - platform: bl0939addr
    id: ch3
    update_interval: 10s
    voltage:
      name: 'v_D'
    current_1:
      name: 'c_D1'
    current_2:
      name: 'c_D2'
    active_power_1:
      name: 'p_D1'
    active_power_2:
      name: 'p_D2'
    energy_1:
      name: 'e_D1'
    energy_2:
      name: 'e_D2'
    energy_total:
      name: 'e_D'
    address: 3
    current_reference: 438921.675
    voltage_reference: 16740.165
    power_reference: 1147.908
    energy_reference: 9852.572

switch:
  - platform: gpio
    pin: 15
    name: "LED"

binary_sensor:
  - platform: gpio
    name: "button"
    pin: GPIO0

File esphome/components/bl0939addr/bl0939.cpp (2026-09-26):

#include "bl0939.h"
#include "esphome/core/log.h"

// #include "esphome/components/uart/uart_component_esp32_arduino.h"

namespace esphome {
namespace bl0939 {

static const char *const TAG = "bl0939";

// https://www.belling.com.cn/media/file_object/bel_product/BL0939/datasheet/BL0939_V1.2_cn.pdf
// (unfortunately chinese, but the protocol can be understood with some translation tool)
static const uint8_t BL0939_READ_COMMAND = 0x50;  // 0x5{A4,A3,A2,A1}
static const uint8_t BL0939_FULL_PACKET = 0xAA;
static const uint8_t BL0939_PACKET_HEADER = 0x55;

static const uint8_t BL0939_WRITE_COMMAND = 0xA0;  // 0xA{A4,A3,A2,A1}
static const uint8_t BL0939_REG_IA_FAST_RMS_CTRL = 0x10;
static const uint8_t BL0939_REG_IB_FAST_RMS_CTRL = 0x1E;
static const uint8_t BL0939_REG_MODE = 0x18;
static const uint8_t BL0939_REG_SOFT_RESET = 0x19;
static const uint8_t BL0939_REG_USR_WRPROT = 0x1A;
static const uint8_t BL0939_REG_TPS_CTRL = 0x1B;

static Mutex bl0939_global_lock;

uint8_t BL0939::write_command() {
  return BL0939_WRITE_COMMAND | this->address_;
}

uint8_t BL0939::read_command() {
  return BL0939_READ_COMMAND | this->address_;
}

void BL0939::loop() {

  if (this->waiting) {
    if (this->available() < sizeof(DataPacket)) {
      if (millis() - this->time_update_start > 1000) {
        ESP_LOGW(TAG, "BL0939 %d did not respond within 1 second. received %d of %d", this->address_, this->available(), sizeof(DataPacket));
        while (read() >= 0);
        this->waiting = false;
        bl0939_global_lock.unlock();
      }
      return;
    }

    DataPacket buffer;
    if (read_array((uint8_t *) &buffer, sizeof(buffer))) {
      if (validate_checksum(&buffer)) {
        received_package_(&buffer);
      }
    } else {
      ESP_LOGW(TAG, "Junk on wire at %d. Throwing away partial message", this->address_);
      while (read() >= 0);
    }
    this->waiting = false;
    ESP_LOGW(TAG, "BL0939 updating %d DONE", this->address_);
    bl0939_global_lock.unlock();
    return;
  }

  if (needs_updating) {
    // another sensor is running - scheduling not possible
    if (!bl0939_global_lock.try_lock()) {
      return;
    }

    needs_updating = false;

    // request data from sensor
    ESP_LOGW(TAG, "BL0939 updating %d", this->address_);

    // this->flush();
    this->write_byte(this->read_command());
    this->write_byte(BL0939_FULL_PACKET);
    this->time_update_start = millis();

    this->waiting = true;
  }
}

bool BL0939::validate_checksum(const DataPacket *data) {
  uint8_t checksum = this->read_command();
  // Whole package but checksum
  for (uint32_t i = 0; i < sizeof(data->raw) - 1; i++) {
    checksum += data->raw[i];
  }
  checksum ^= 0xFF;
  if (checksum != data->checksum) {
    ESP_LOGW(TAG, "BL0939 %d invalid checksum! 0x%02X != 0x%02X", this->address_, checksum, data->checksum);
  }
  return checksum == data->checksum;
}

void BL0939::update() {
  ESP_LOGW(TAG, "BL0939 request update %d", this->address_);
  needs_updating = true;
}

void BL0939::setup() {
  delay(1000);
  needs_updating = false;
  time_update_start = 0;
  waiting = false;

  // force 1.5 stop bits - works only on arduino esp32 backend
  // esphome::uart::ESP32ArduinoUARTComponent* dev = reinterpret_cast<esphome::uart::ESP32ArduinoUARTComponent*>(this->parent_);
  // auto serial = dev->get_hw_serial();
  // serial->begin(4800, 134217772);

  const uint8_t BL0939_INIT[6][6] = {
    // Reset to default
    {this->write_command(), BL0939_REG_SOFT_RESET, 0x5A, 0x5A, 0x5A, 0x33},
    // Enable User Operation Write
    {this->write_command(), BL0939_REG_USR_WRPROT, 0x55, 0x00, 0x00, 0xEB},
    // 0x0100 = CF_UNABLE energy pulse, AC_FREQ_SEL 50Hz, RMS_UPDATE_SEL 800mS
    {this->write_command(), BL0939_REG_MODE, 0x00, 0x10, 0x00, 0x32},
    // 0x47FF = Over-current and leakage alarm on, Automatic temperature measurement, Interval 100mS
    {this->write_command(), BL0939_REG_TPS_CTRL, 0xFF, 0x47, 0x00, 0xF9},
    // 0x181C = Half cycle, Fast RMS threshold 6172
    {this->write_command(), BL0939_REG_IA_FAST_RMS_CTRL, 0x1C, 0x18, 0x00, 0x16},
    // 0x181C = Half cycle, Fast RMS threshold 6172
    {this->write_command(), BL0939_REG_IB_FAST_RMS_CTRL, 0x1C, 0x18, 0x00, 0x08}};

  for (auto *i : BL0939_INIT) {
    this->write_array(i, 6);
    delay(1);
  }
  this->flush();

  // the soft reset above does not clear CF_CNT; the first packet sets the baseline
  this->have_baseline_ = false;
  this->energy_pulses_[0] = this->energy_pulses_[1] = 0;
  this->last_packet_ms_ = millis();

  bl0939_global_lock.unlock();
}

void BL0939::received_package_(const DataPacket *data) {
  // Bad header
  if (data->frame_header != BL0939_PACKET_HEADER) {
    ESP_LOGI("bl0939", "BL0939 %d invalid data. Header mismatch: %d", this->address_, data->frame_header);
    return;
  }

  float v_rms = (float) to_uint32_t(data->v_rms) / voltage_reference_;
  float ia_rms = (float) to_uint32_t(data->ia_rms) / current_reference_;
  float ib_rms = (float) to_uint32_t(data->ib_rms) / current_reference_;
  float a_watt = (float) to_int32_t(data->a_watt) / power_reference_;
  float b_watt = (float) to_int32_t(data->b_watt) / power_reference_;
  uint32_t cfa_cnt = to_uint32_t(data->cfa_cnt);
  uint32_t cfb_cnt = to_uint32_t(data->cfb_cnt);
  uint32_t now_ms = millis();
  if (!this->have_baseline_) {
    this->last_cf_cnt_[0] = cfa_cnt;
    this->last_cf_cnt_[1] = cfb_cnt;
    this->have_baseline_ = true;
  }
  // max plausible pulses since the last packet: max_power [W] over dt, in kWh, times pulses per kWh
  float dt_h = (float) (now_ms - this->last_packet_ms_) / 3.6e6f;
  int32_t max_delta = (int32_t) (this->max_power_ / 1000.0f * dt_h * this->energy_reference_) + 1;
  this->energy_pulses_[0] += cf_delta(this->last_cf_cnt_[0], cfa_cnt, max_delta);
  this->energy_pulses_[1] += cf_delta(this->last_cf_cnt_[1], cfb_cnt, max_delta);
  this->last_cf_cnt_[0] = cfa_cnt;
  this->last_cf_cnt_[1] = cfb_cnt;
  this->last_packet_ms_ = now_ms;
  float a_energy_consumption = (float) this->energy_pulses_[0] / energy_reference_;
  float b_energy_consumption = (float) this->energy_pulses_[1] / energy_reference_;
  float total_energy_consumption = (float) (this->energy_pulses_[0] + this->energy_pulses_[1]) / energy_reference_;

  if (voltage_sensor_ != nullptr) {
    voltage_sensor_->publish_state(v_rms);
  }
  if (current_sensor_1_ != nullptr) {
    current_sensor_1_->publish_state(ia_rms);
  }
  if (current_sensor_2_ != nullptr) {
    current_sensor_2_->publish_state(ib_rms);
  }
  if (power_sensor_1_ != nullptr) {
    power_sensor_1_->publish_state(a_watt);
  }
  if (power_sensor_2_ != nullptr) {
    power_sensor_2_->publish_state(b_watt);
  }
  if (energy_sensor_1_ != nullptr) {
    energy_sensor_1_->publish_state(a_energy_consumption);
  }
  if (energy_sensor_2_ != nullptr) {
    energy_sensor_2_->publish_state(b_energy_consumption);
  }
  if (energy_sensor_sum_ != nullptr) {
    energy_sensor_sum_->publish_state(total_energy_consumption);
  }
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

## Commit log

2023-02-23 lower PCB first iteration
    [lower-pcb.PcbDoc, lower-pcb.PrjPcb, lower-pcb.SchDoc]
2023-02-23 assembly step
2023-02-23 fix mechanical collisions
    [lower-pcb.PcbDoc, lower-pcb.SchDoc]
2023-02-24 update holes location'
    [lower-pcb.PcbDoc, lower-pcb.SchDoc]
2023-02-24 upper PCB template
    [upper-pcb.PcbDoc, upper-pcb.PrjPcb, upper-pcb.SchDoc]
2023-02-24 upper pcb BL0939
    [upper-pcb.PcbDoc, upper-pcb.SchDoc]
2023-05-11 Routed PCBs
    [channel.SchDoc, lower-pcb.PcbDoc, lower-pcb.SchDoc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]
2023-12-24 production run v0.1
    [channel.SchDoc, lower-pcb.PrjPcb, lower-pcb.SchDoc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]
2023-12-24 use one UART, fix addresses
    [channel.SchDoc, upper-pcb.PcbDoc, upper-pcb.PrjPcb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]
2024-01-12 assembly files
    [BOM.xlsx, lower-pcb.PrjPcb, upper-pcb.PrjPcb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]
2024-01-15 sch/pcb prepared for production
    [BOM.xlsx, channel.SchDoc, lower-pcb.PcbDoc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]
2024-01-15 jlcpcb outjob
    [lower-pcb.PrjPcb, upper-pcb.PrjPcb]
2024-01-15 update assembly step
2024-01-16 change XHB connector
    [BOM.xlsx]
2024-01-16 total BOM
    [BOM.xlsx]
2024-02-15 Enhance logs with sensor ID
2024-02-21 add 10uF capacitors on VBUS and EN line
    [BOM.xlsx, channel.SchDoc, upper-pcb.PrjPcb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]
2024-02-21 add silkscreen, update gerbers
2024-02-21 increase pad size for ARK connectors
    [lower-pcb.PcbDoc, lower-pcb.PrjPcb]
2024-03-02 production release candidate
    [lower-pcb.PrjPcb, lower-pcb.step, upper-pcb.PrjPcb]
2024-03-02 rename output files
    [lower-pcb-BOM.xlsx, upper-pcb-BOM.xlsx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]
2024-04-09 fix neutral connector note
2026-09-26 fix energy counter wrap: read CF_CNT unsigned, accumulate signed deltas
    BL0939 CFA_CNT/CFB_CNT are 24-bit unsigned counters (datasheet 1.2) that
    count energy pulses algebraically and wrap at 2^24. The driver read them
    as signed 24-bit, so energy flipped negative at 2^23 pulses (851 kWh with
    the default energy_reference) and would jump back to 0 at 2^24 (1702 kWh).
    Now the firmware keeps an int64 pulse accumulator per sub-channel and adds
    the sign-extended 24-bit delta between consecutive readings, so wraps in
    either direction are transparent and PV export still subtracts. A delta
    larger than max_power (new yaml key, default 10000 W) times the elapsed
    time is treated as the chip having reset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
    [bl0939.cpp]
2026-09-26 take energy baseline on first packet: reboot restarts energy at 0
    SOFT_RESET does not clear CFA_CNT/CFB_CNT (verified on a device: energy
    survived an OTA reboot), so re-syncing the accumulator to the raw counter
    after a reboot would read it as signed 24-bit again and flip negative past
    2^23 pulses. Instead the first packet after boot only sets the baseline:
    energy restarts at 0 on every reboot, same as after a power cycle, and HA
    handles it as a meter reset.
    [bl0939.cpp]
2026-10-14 adds WA_CREEP setting to filter bad negative watts
2026-10-14 fix init checksums: write config via write_reg24_ for any address
    The init table had checksums hardcoded for address 5 (0xA5), so chips at
    addresses 0-3 rejected every frame and ran on chip defaults. Registers are
    now written with computed checksums and read back; a mismatch logs a warning.
    - unlock before SOFT_RESET too (USR_WRPROT guards it), unlock again after
    - MODE comment fixed: 0x1000 is CF as alarm output, RMS update 400 ms
    - WA_CREEP joins the table, so its separate unlock is gone
2026-10-14 init: wait after SOFT_RESET, report readback failures in dump_config
    With PR #5 flashed, WA_CREEP 0x2F did not take effect: frames sent right
    after the (now working) soft reset seem to be dropped. Flush and wait 50 ms
    after the reset. Readback mismatches are now logged from dump_config, so they
    show on every API log connection, not only in the boot log.
